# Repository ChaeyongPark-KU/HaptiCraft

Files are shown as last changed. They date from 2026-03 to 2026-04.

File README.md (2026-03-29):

# HaptiCraft: A Modular Multimodal Haptic Controller for Immersive VR

**HaptiCraft** is a modular, reconfigurable handheld controller designed to replicate the physical appearance, mass distribution, and rich multimodal haptic properties of virtual objects. By assembling cubic modules with distinct functions, users can create a customized physical proxy tailored to specific VR interactions.

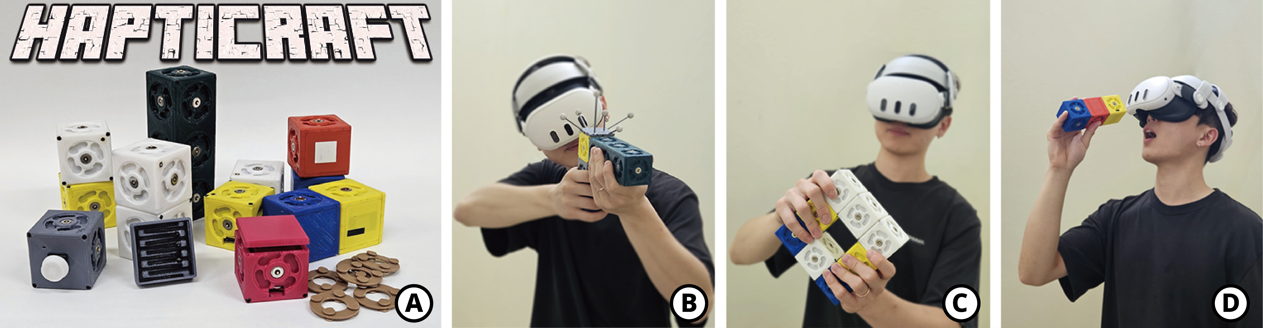
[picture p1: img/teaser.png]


## Key Features

* **Modular Shape Approximation**: Uses unit cube modules ($48 \times 48 \times 48$ mm) to build controllers that mimic the shape of virtual counterparts.
* **Multimodal Feedback**: Supports five distinct active haptic stimuli: **Vibration**, **Impact**, **Thermal**, **Variable Inertia**, and **Variable Stiffness**.
* **Dynamic Property Matching**: Features a variable inertia module that shifts internal mass to match the Moment of Inertia (MOI) of virtual objects.
* **Integrated Authoring Tool**: Includes a graphical "What-You-See-Is-What-You-Get" (WYSIWYG) tool for designing both physical forms and complex haptic timelines.

## System Architecture

HaptiCraft is built on three foundational pillars:

1.  **Hardware**: 3D-printed (PLA) modules containing MCUs (Wemos D1 mini; ESP8266), actuators, and a secure mechanical connection mechanism.
2.  **Firmware**: ESP8266-based code managing assembly detection, wireless mesh synchronization, and real-time haptic command execution.
3.  **Software**: A Unity-based authoring tool that exports designs in the **HaptiCraft Description Format (.hdf)**, a JSON-based schema for easy integration into VR projects.

## Repository Structure

This repository is organized into three main components:

* **/Hardware**: Includes CAD files (STL) for module housings and circuit schematics for the haptic drivers.
* **/Firmware**: ESP8266 source code for the Wi-Fi mesh communication and haptic rendering protocols.
* **/Software**: The Unity source code for the HaptiCraft authoring tool.

## Examples
### Haptic Modules
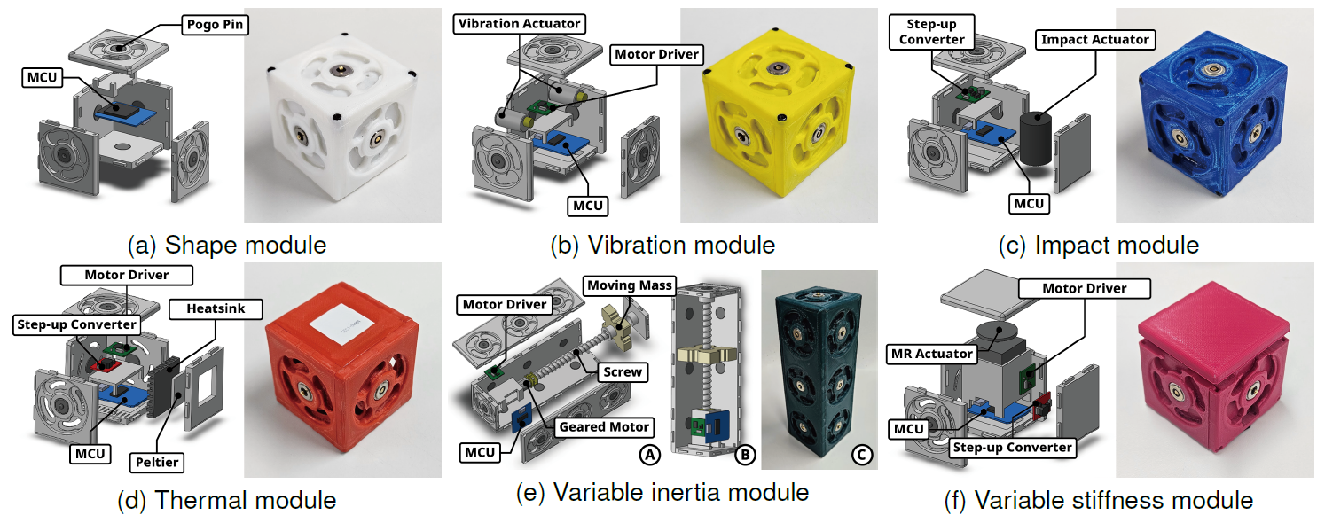
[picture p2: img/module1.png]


### utility Module and Connector
<p align="center">
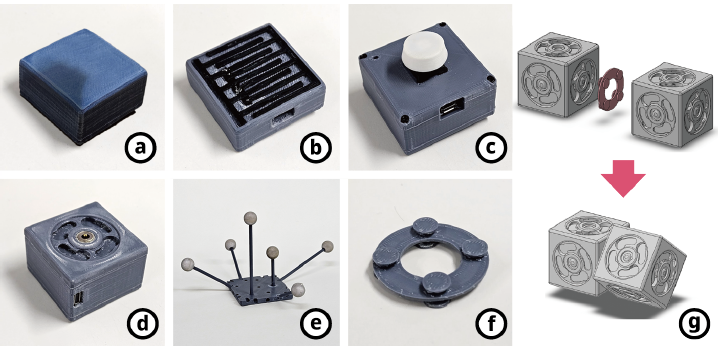
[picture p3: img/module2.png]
  
</p>

### Controller Authoring Tool
<p align="center">
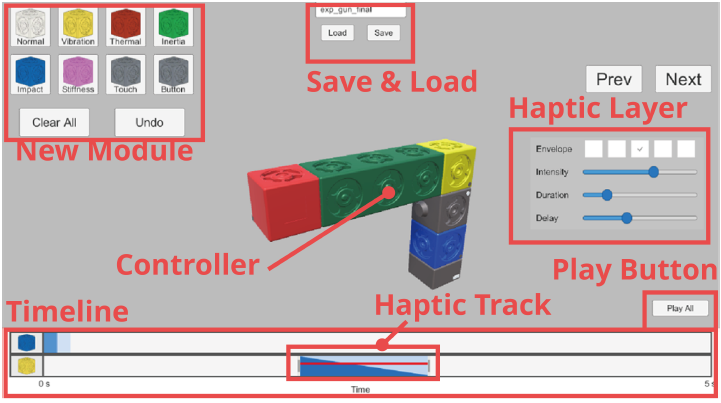
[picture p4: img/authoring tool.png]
  
</p>

## Citation
If you use HaptiCraft in your research, please cite our paper:
```
@article{Park2026HaptiCraft,
author = {Park, Chaeyong and Kim, Jeongwoo and Song, Yuk-Gwon and Kim, Sang-Youn and Choi, Seungmoon},
title = {HaptiCraft: A Modular Multimodal Haptic Controller for Immersive Virtual Reality Interactions},
journal = {IEEE transactions on visualization and computer graphics},
volume={XX},
number={X},
pages={XXXX--XXXX},
year={2026},
publisher={IEEE}
}
```

## Issues
If you encounter any issues, please feel free to contact us at chaeyong@korea.ac.kr.

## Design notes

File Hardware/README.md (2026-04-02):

# HaptiCraft Hardware

This folder contains the CAD files (STL) and electronic specifications for the **HaptiCraft** system. All haptic and utility modules are built around the [**ESP8266-based Wemos D1 Mini**](https://www.wemos.cc/en/latest/d1/d1_mini.html).

## Manufacturing & Assembly

* **3D Printing**: All housings are designed for modular assembly. For this research, parts were printed using a **Cubicon Single Plus 320C** with PLA filament. But, you can use any 3D printer for printing.
* **Module Faces**: Each STL file corresponds to a specific side of a cube, designed to be easily printed and assembled to house internal components.
* **Power & Connection**: Modules use [**magnetic pogo pins**](https://duertry.com/r/v2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) at the center of each face to enable both structural bonding and power sharing (up to 12V, 10A) across the entire assembly.

## Module-Specific Hardware Descriptions
Follow the schematics provided in this directory for each specific module type:

### 1. Shape Module
The structural unit of the system. It consists of the 3D-printed housing, the MCU, and 6 Pogo pins for connectivity, with no active haptic actuators.

<p align="center">
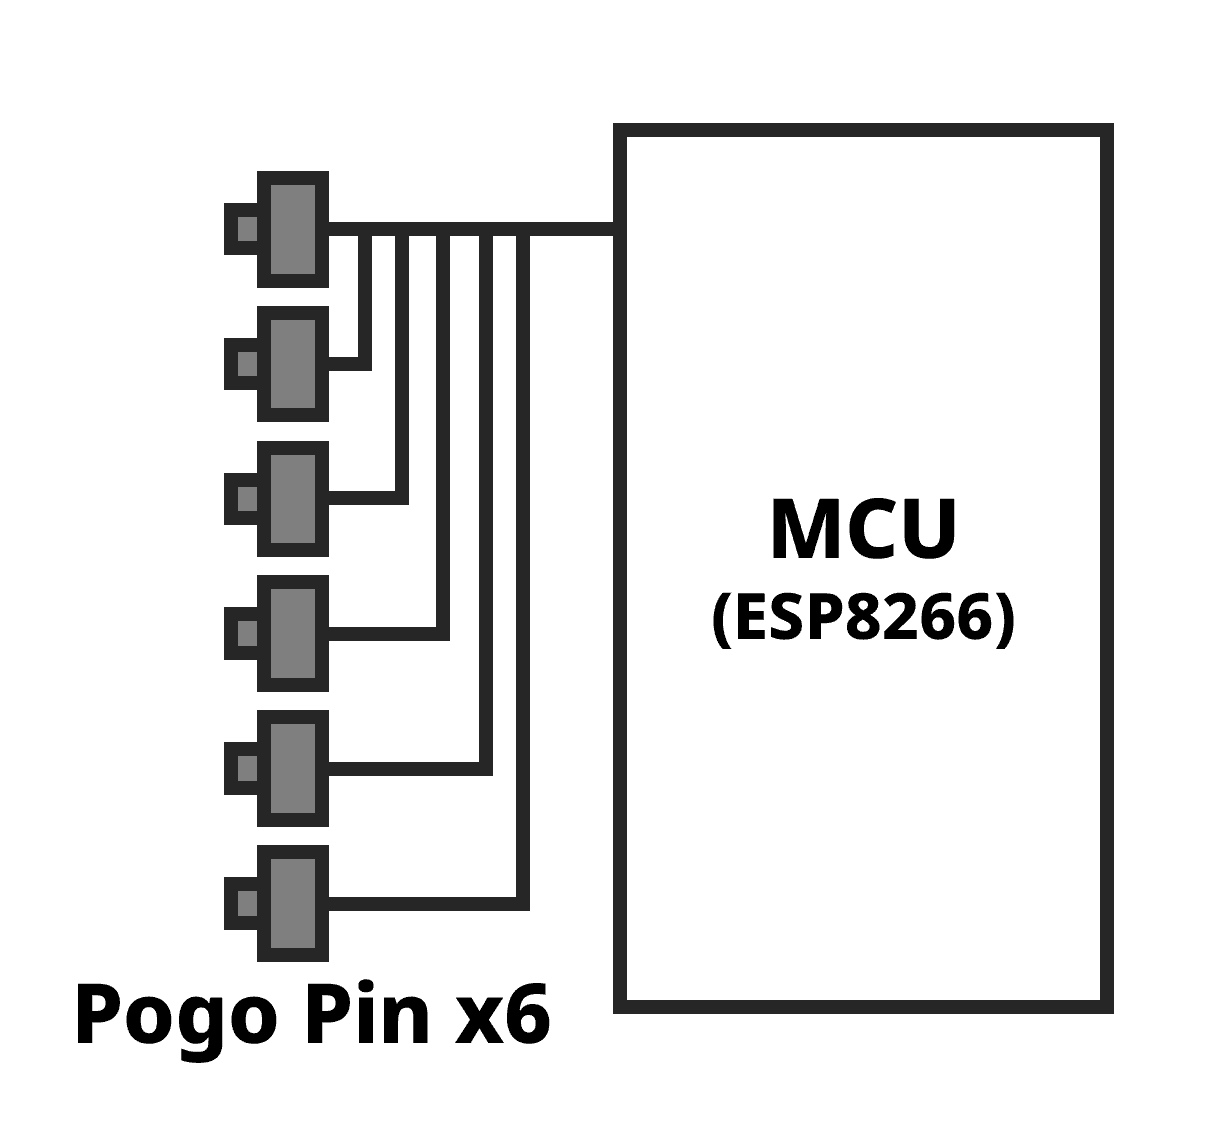
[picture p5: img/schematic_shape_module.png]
   
</p>

### 2. Vibration Module
Uses a motor driver to power two ERM motors for stable vibrotactile feedback.
* **ERM**: [D&J WITH Co., Ltd.; DVM1220](https://www.devicemart.co.kr/goods/view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).
* **Motor Driver**: [Pololu; BD65496MUV](https://www.rohm.co.kr/products/motor-actuator-drivers/dc-brush-motor/bd65496muv-product#productDetail).

<p align="center">
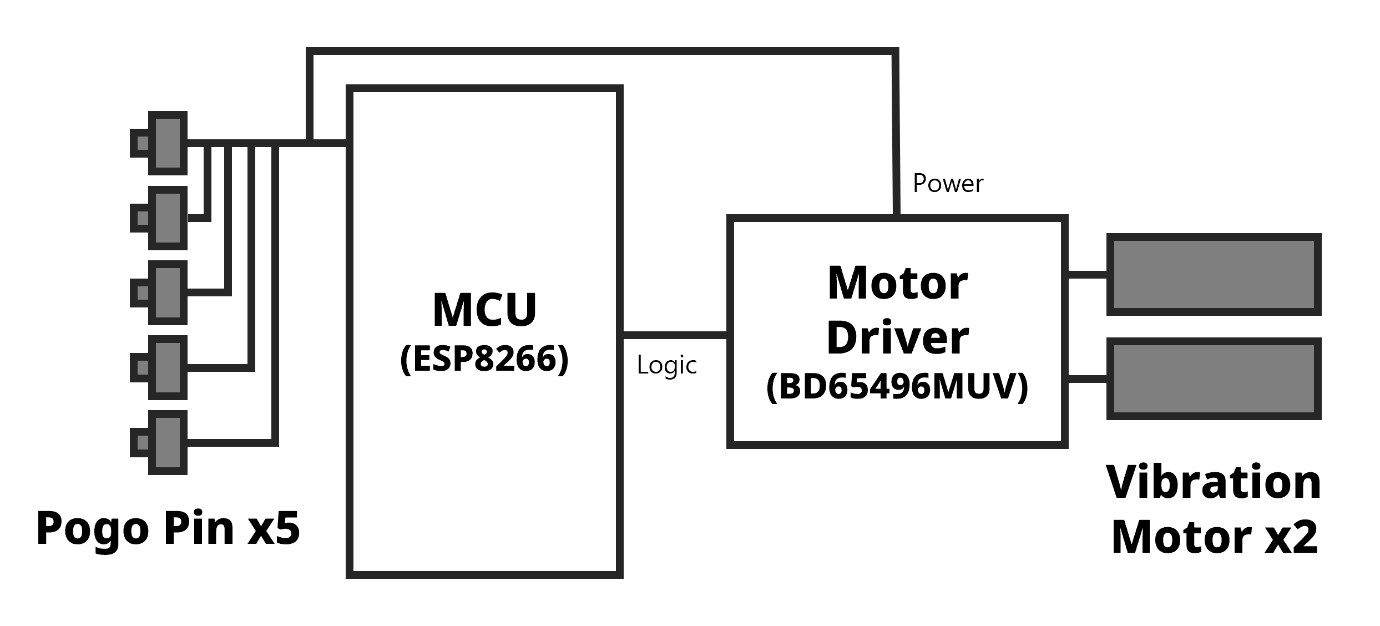
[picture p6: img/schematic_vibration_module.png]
   
</p>

### 3. Impact Module
Delivers short, strong impulses. Since it requires 5V, a step-up converter is integrated into the circuit.
* **Actuator**: [Acturonix; Digital Haptic Actuator](https://www.acturonix.com/).
* **Converter**: [WSTECH; DM06-V5](m.eleparts.co.kr/goods/view?no=4107103).

<p align="center">
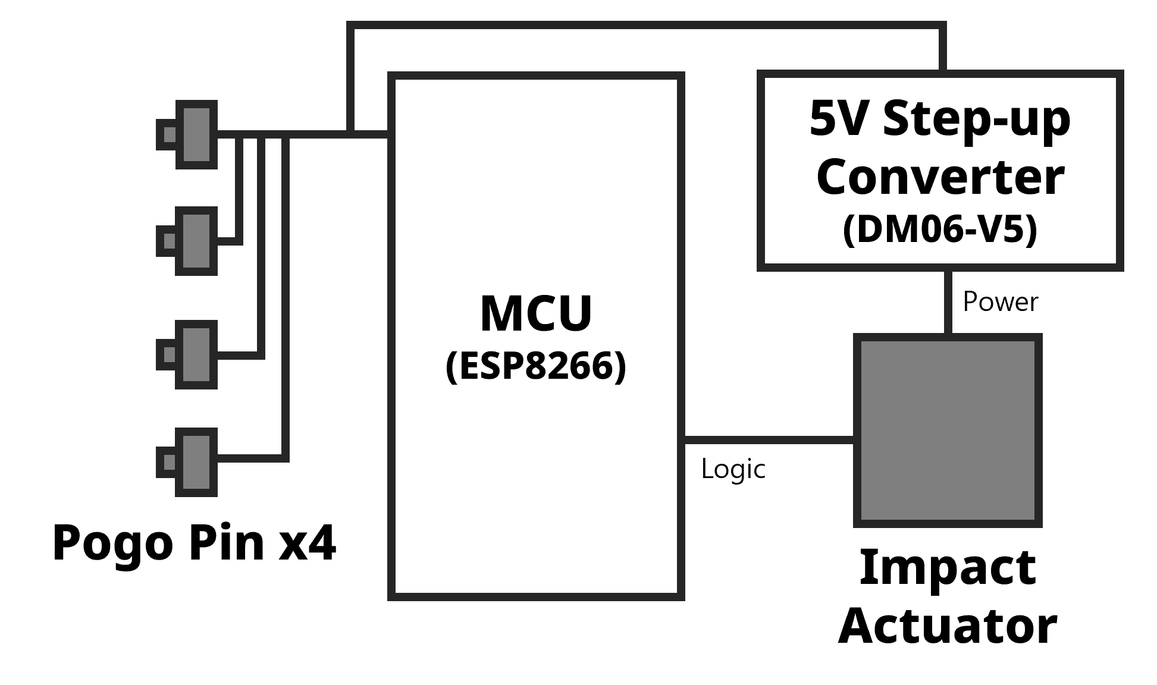
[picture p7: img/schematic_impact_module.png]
   
</p>

### 4. Thermal Module
Provides temperature feedback using a Peltier element. The assembly includes a step-up converter, motor driver, and a heatsink for effective thermal management.
* **Peltier**: [20×20 mm; SMG TES1-4903](https://www.devicemart.co.kr/goods/view?no=10894480).
* **Motor Driver**: [Pololu; BD65496MUV](https://www.rohm.co.kr/products/motor-actuator-drivers/dc-brush-motor/bd65496muv-product#productDetail).
* **Converter**: [WSTECH; DM13-V5](https://www.navimro.com/p/K92841578/?srsltid=AfmBOopcCdm5g3zLqHN5-aAA_jKeQ_9SND-a58UxNgDZ9oHb2oCQjKNd).

<p align="center">
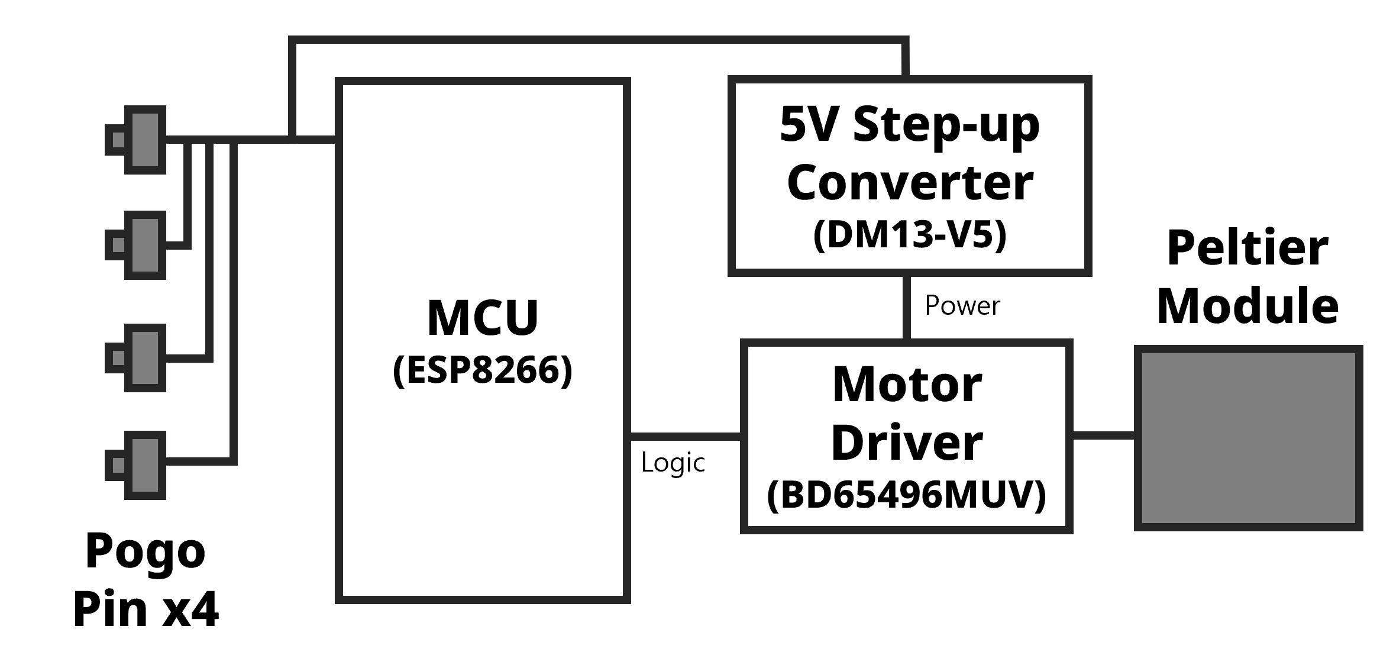
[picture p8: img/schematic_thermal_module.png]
   
</p>

### 5. Variable Inertia Module
Converts rotational motion into linear motion via a geared motor to shift the position of a **brass moving mass**. The moving mass can be weighted further using the uploaded weight-add files.
* **Gear Motor**: [N20; SZH-GNP095](https://www.icbanq.com/P008113428?srsltid=AfmBOoqd4h_dOW6KhbtmznncK5vQkRHJzLvjkogEKoTrAjK_nVLmlyeV).
* **Motor Driver**: [Pololu; BD65496MUV](https://www.rohm.co.kr/products/motor-actuator-drivers/dc-brush-motor/bd65496muv-product#productDetail).

<p align="center">
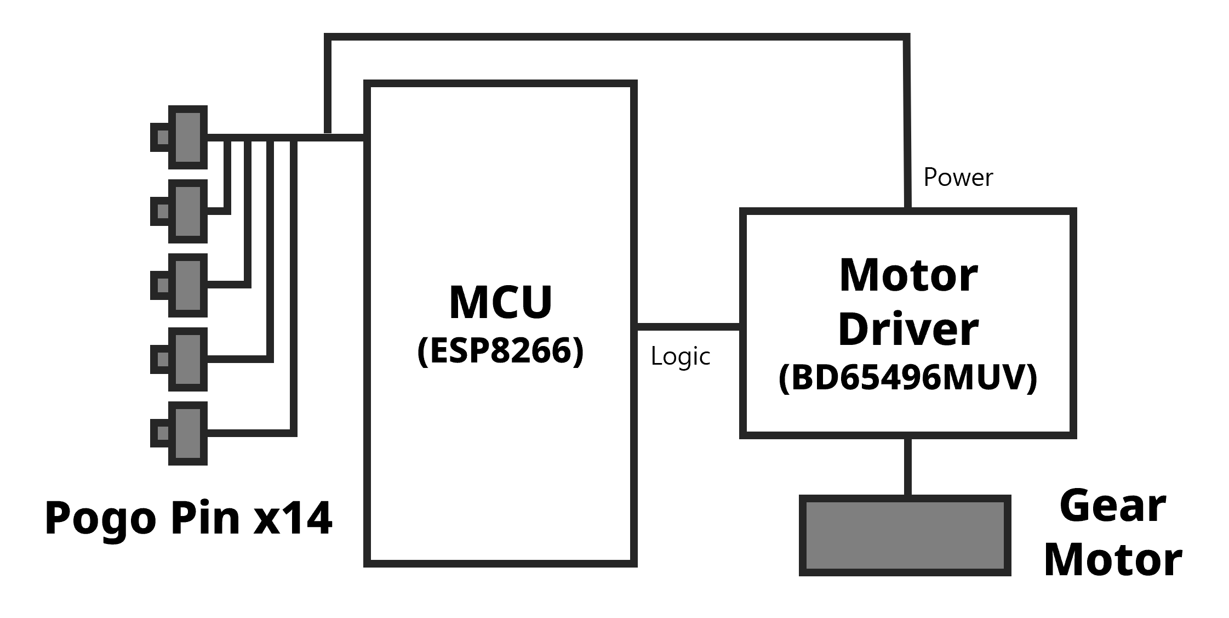
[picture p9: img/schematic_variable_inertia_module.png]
   
</p>

### 6. Variable Stiffness Module
Adjusts surface softness using a custom variable-damping actuator. The internal circuit is based on the mechanism described in [[46]](https://journals.sagepub.com/doi/10.1177/1045389X13493359). All necessary CAD files for the spring-loaded structure are provided.

<p align="center">
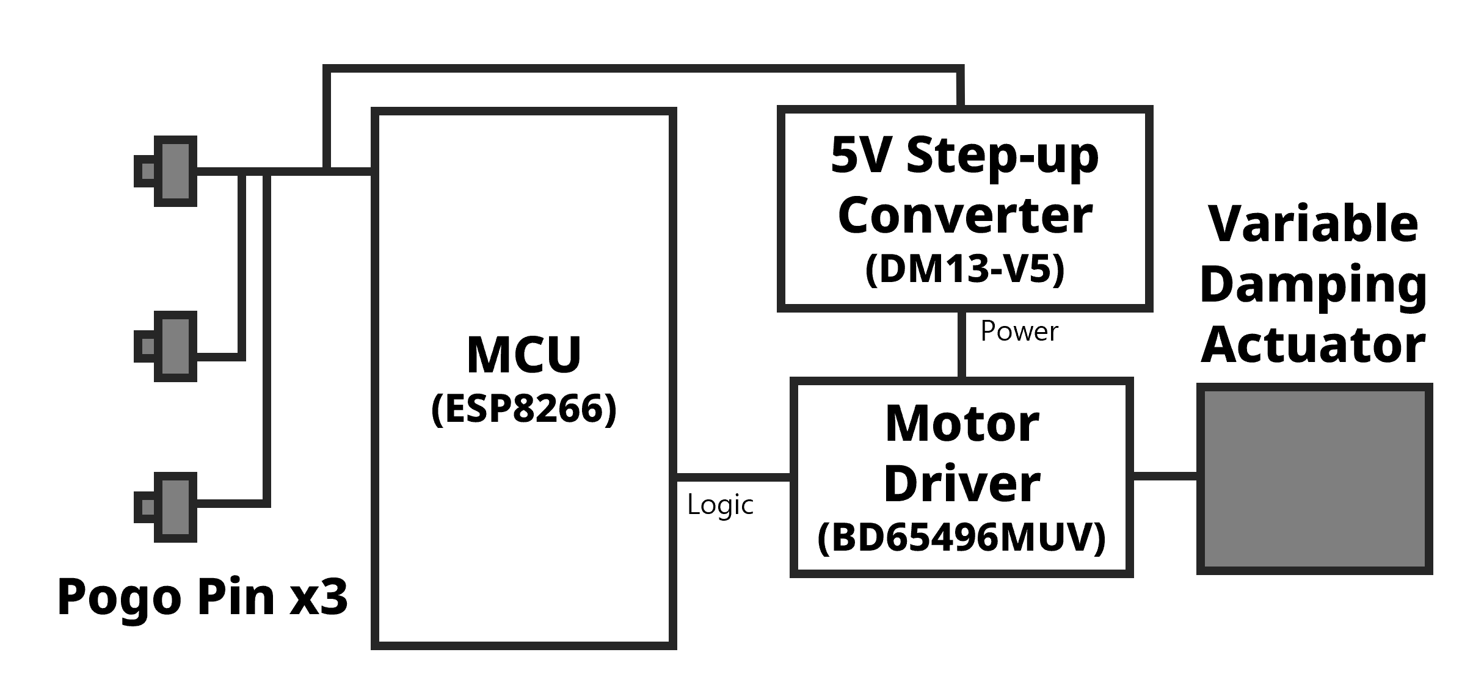
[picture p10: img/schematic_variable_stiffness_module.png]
   
</p>

### 7. Communication Module
A utility module containing only the MCU. It must be loaded with the `masterModule` firmware to act as the serial-to-mesh gateway.

### 8. Button Module
A 3D-printed housing embedded with a standard **mechanical keyboard switch** (linear switch) for user input.

<p align="center">
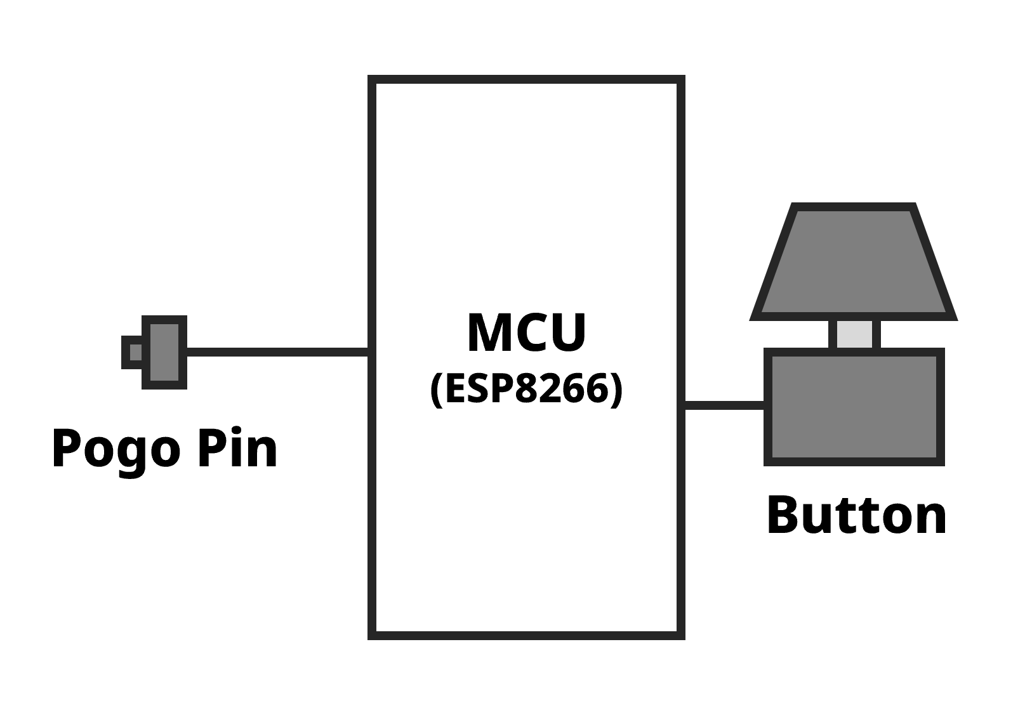
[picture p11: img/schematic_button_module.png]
   
</p>

### 9. Touch Module
The top panel is printed using **conductive filament**. The circuit detects a touch when a finger bridges the filament paths, completing the electrical connection.

<p align="center">
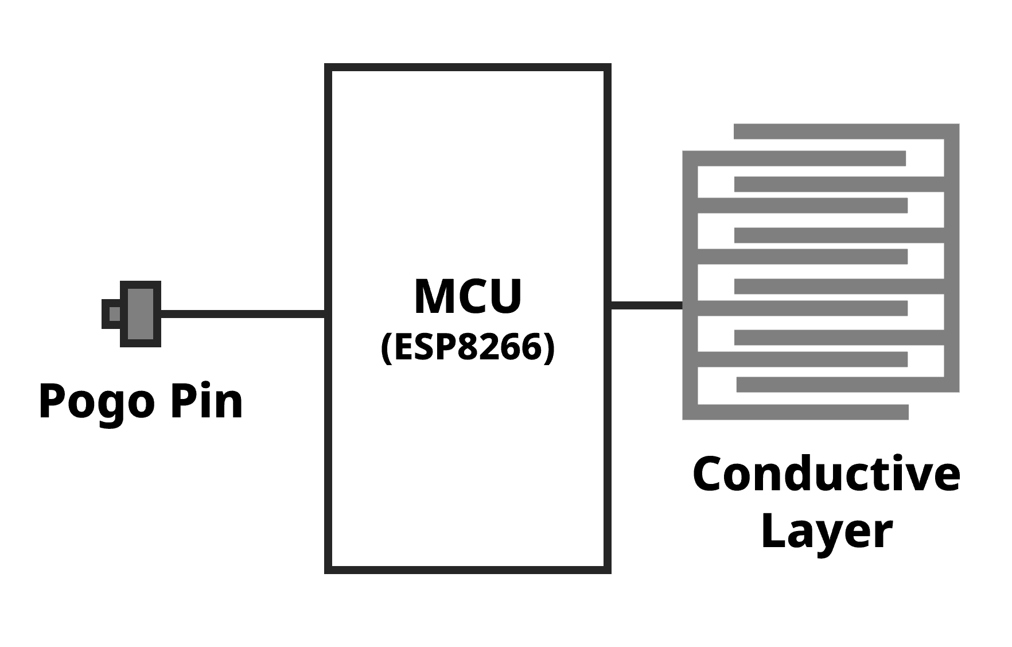
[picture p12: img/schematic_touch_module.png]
   
</p>

### 10. Power Module
Houses a **LiPo battery** (3.7V, 1200 mAh) and a charging circuit to provide untethered power to the entire HaptiCraft assembly.

<p align="center">
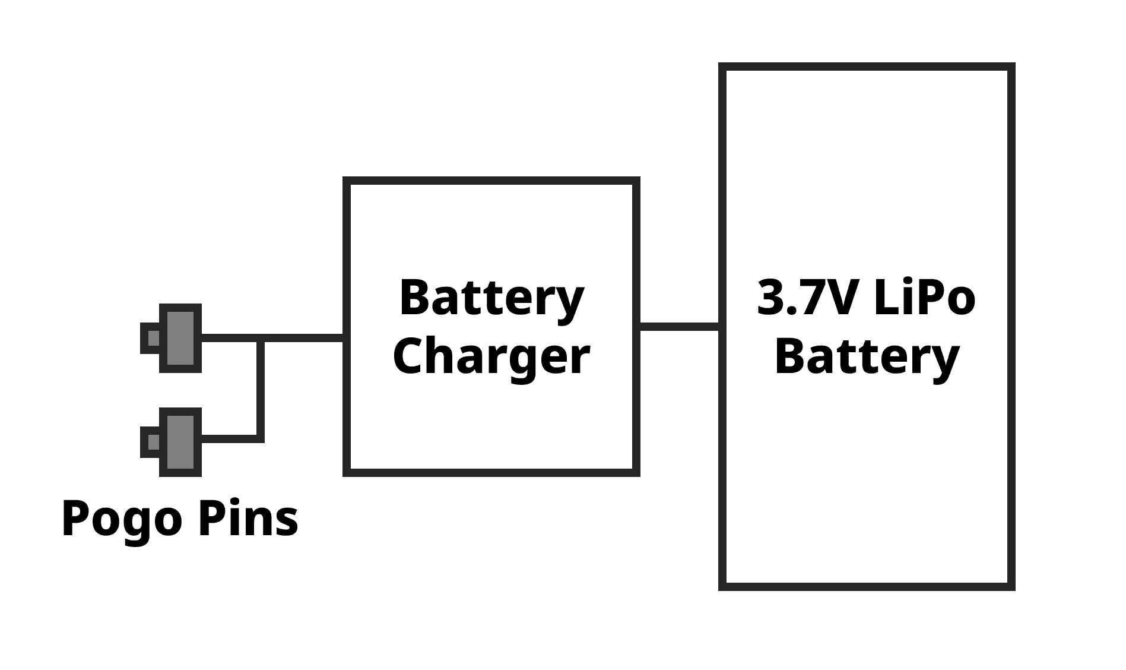
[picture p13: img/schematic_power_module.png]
   
</p>

### 11. Tracking Module
Supports optical tracking (e.g., [Optitrack](https://optitrack.com/)). It is recommended to print various pillars and body types to create unique rigid-body marker configurations for VR tracking.

### 12. Connector Module
A 3D-printed part featuring four embossed poles that secure the mechanical connection between modules.

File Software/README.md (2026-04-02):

# **HaptiCraft Authoring Tool**

HaptiCraft authoring tool is a Unity-based tool designed for creating modular haptic controllers and designing custom haptic feedback patterns. This tool supports the entire workflow from virtual assembly to physical implementation and haptic signal synchronization.

<p align="center">
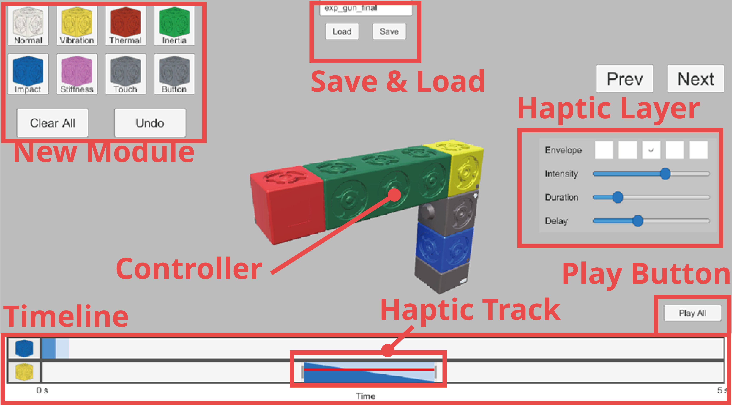
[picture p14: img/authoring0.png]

</p>

## **Preparation**

### **Hardware Requirements**

- **Communication Module:** Connect a communication module to your PC via USB.
- **Serial Port:** Identify the COM port number (Windows) assigned to the communication module.

### **Software Requirements**

- **Unity Version:** Tested and verified on **Unity 2022.3 (LTS)**.
- **Package:** Import the provided `.unitypackage` into your Unity project.

### **Project Configuration**

1. Go to **Project Settings \> Player \> Configuration**.
2. Set **Api Compatibility Level** to **.NET Framework**.
3. Open the main scene: Assets/Scenes/HaptiCraft.unity.
4. In the **Hierarchy**, find Authoring Utils \-\> Serial Manager.
5. Set the **Port Number** in the Inspector to match your communication module's serial port.

## **Basic Controls**

<p align="center">

| **Action** | **Input** |
| --- | --- |
| **Rotate Controller** | Left Click \+ Drag  |
| **Move Controller** | Wheel Click \+ Drag |
| **Zoom In / Out** | Wheel Scroll |
</p>

## **Authoring Workflow**

The tool consists of three main phases to guide you through the creation process.

### **1\. Controller Design Phase**

This is where you design the physical structure of your virtual modular controller.

<p align="center">
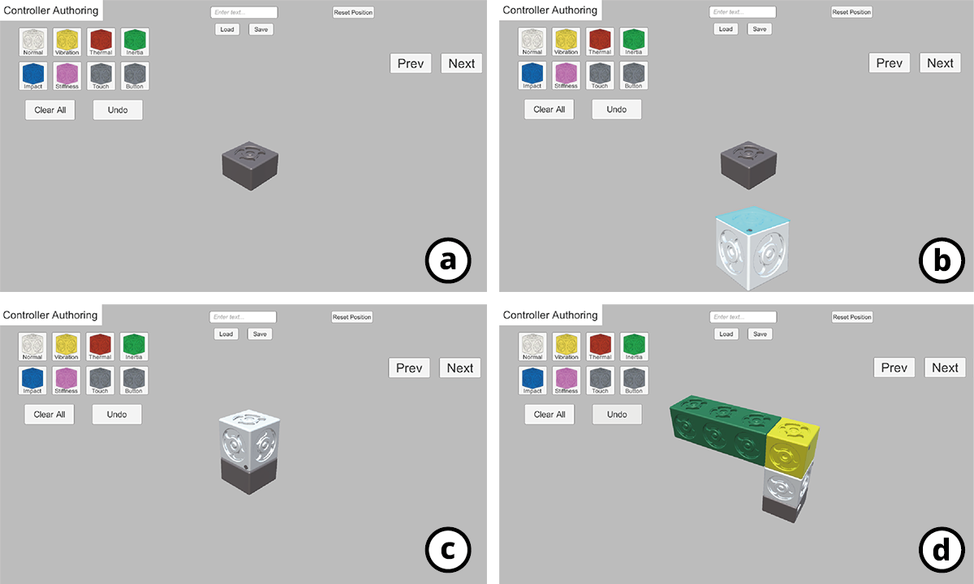
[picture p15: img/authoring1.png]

</p>

- **Add Modules:** Click the module buttons (top-left) to spawn a module at the bottom-center of the screen.
- **Connect Modules:** Select a specific face of the new module and then the face on the existing controller you wish to connect to.
- **Rotate:** Use the **Arrow Keys** to rotate the module before finalizing.
- **Confirm:** Press the **Return (Enter)** key to finalize the connection.
- **Next:** Once the controller is finished, click the **Next** button (top-right).

### **2\. Haptic Assembly Phase**

Design and edit haptic signals for the assembled controller.

<p align="center">
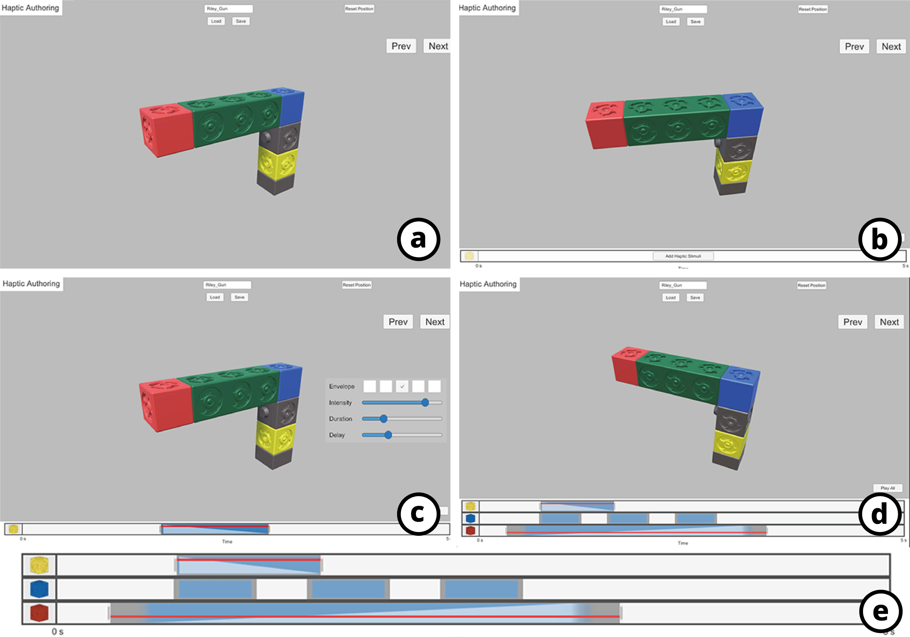
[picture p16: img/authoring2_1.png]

</p>

- **Module Selection:** Left-click on any haptic-capable module to create a stimulus.
- **Edit Haptic Effects:** Use the **Haptic Layer** (right) and the **Timeline/Haptic Track** (bottom) to adjust the timing, duration, and intensity of the feedback.

### **3\. Implementation Phase**

This phase helps you assemble the physical hardware corresponding to your virtual design.

- **Assembly Guide:** Starting from `Power module`, the virtual module to be connected next will **blink**.
- **Detection:** Once `Communication Module` recognizes the physical connection, the next module in the sequence will start blinking.
- **Skip:** You can skip this phase and proceed to the next by clicking the **Next** button without connecting physical modules.

#### **Supported Modules:**

- **Vibration Module:** Envelope, Intensity, Duration, Delay.
- **Thermal Module:** Mode (Cold / Hot), Intensity, Duration, Delay.
- **Inertia Module:** Direction, Duration.
- **Impact Module:** Repetition, Delay.
- **Stiffness Module:** _(Currently disabled)_
- **Button Module:** Click detection.
- **Touch Module:** Touch detection.

## **Save / Load**

You can save or load your controller designs and haptic patterns at any time.

- Enter a filename in the **Input Field** at the top of the screen.
- Click **Save** to store the current configuration or **Load** to restore a previous one.

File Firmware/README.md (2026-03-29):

# HaptiCraft Firmware

This folder contains the ESP8266-based firmware for the **HaptiCraft** system. The system operates on a **Master-Slave architecture** using a Wi-Fi mesh network to deliver synchronized, multimodal haptic feedback.

## System Architecture

The firmware is divided into two primary roles:

### 1. Master Module (`/masterModule`)
The Master Module (referred to as the **Communication Module** in the paper) serves as the central bridge between the PC and the haptic controller.
* **Serial Gateway**: Receives high-level haptic commands from the PC via Serial communication (115200 baud).
* **Mesh Management**: Manages a list of all physically connected haptic modules, assigning names and tracking their connection status.
* **Connection Checker**: Periodically broadcasts check signals ("D") to verify if modules are still attached; it automatically removes timed-out nodes from the registry.
* **Command Broadcasting**: Parses PC commands and broadcasts them to the entire Wi-Fi mesh.

### 2. Haptic Modules (`/hapticModule`)
Every individual haptic module runs the same unified firmware, with its specific behavior defined by a module-type constant.
* **Multimodal Execution**: Supports Vibration (ERM), Thermal, Variable Inertia, Impact, and Variable Stiffness.Each module contains its own scheduler to handle timing-critical tasks like PWM generation for waveforms.
* **Input Detection**: Input modules (Touch/Button) detect user interaction and send status updates ("CO" for contact on, "CF" for contact off) back to the Master.

## Communication Flow
<p align="center">
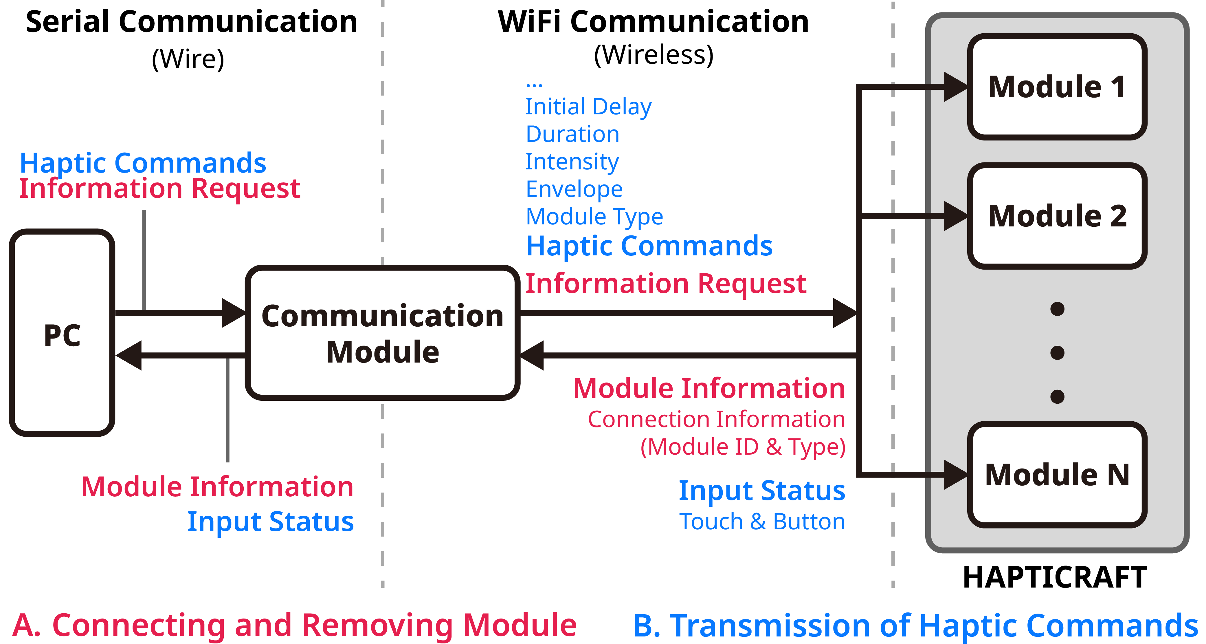
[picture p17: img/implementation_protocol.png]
   
</p>

Refer to the diagram below for the data transmission path:

1.  **PC &rarr; Master**: Sends encoded strings (e.g., `$11V101000`) via Wire.
2.  **Master &rarr; Mesh**: Broadcasts the command wirelessly to all nodes.
3.  **Haptic Module**: If the `nodeName` matches the prefix in the command, the module parses the parameters and triggers the actuator.

## Configuration & Upload

### 1. Prerequisites
* **Hardware**: Wemos D1 Mini (ESP8266).
* **Libraries**: 
    * `painlessMesh` (for Wi-Fi Mesh networking).
    * `ArduinoVector` (for node management).
    * `ArduinoJson` (required by painlessMesh).

### 2. Defining Module Types
Before uploading to a **Haptic Module**, you must define its identity in `moduleDefinition.h`:

```cpp
// moduleDefinition.h
#define VIBERM // Uncomment the specific module type (VIBERM, THERM, IMPACT, etc.)
String nodeName = "11"; // Set a unique 2-digit ID for the module
```

Here is the updated **Command Format** section for your `README.md`. This version specifically reflects the broadcasting logic found in your `masterModule.ino` and the parsing behavior in `hapticModule.ino`.

### 3. Command Format & Broadcasting Logic

HaptiCraft utilizes a **Global Broadcast** strategy to ensure synchronized multimodal effects across multiple modules.

#### **Transmission Protocol**
1.  **PC → Master**: The PC generates a single aggregated string containing all haptic instructions for the intended modules. This string starts with the `$` prefix and appends information for every module to be operated.
2.  **Master → Mesh**: The Master Module identifies the `$` header from the serial input and **broadcasts the command exactly as received** to the entire Wi-Fi mesh network using `mesh.sendBroadcast(inString)`.
3.  **Module-Side Parsing**:
    * Every Haptic Module in the mesh receives the full broadcasted string.
    * Each module parses the string to find segments that begin with its own unique `nodeName` (e.g., "11").
    * If a match is found, the module extracts the specific haptic parameters, stores them in a local command buffer, and executes the rendering task.

#### **Command Syntax**
The aggregated string sent by the PC follows this structure: `$[ModuleID][Command],[ModuleID][Command]...`

| Module Type | Haptic Command (Example) | Description |
| :--- | :--- | :--- |
| **Vibration** | `11V[Env][Int][Dur][Del]` | `11V1101005`: Flat, max intensity, 1s duration, 0.5s delay. |
| **Thermal** | `21T[Dir][Int][Dur][Del]` | `21T1105010`: Hot, max intensity, 5s duration, 1s delay. |
| **Variable Inertia** | `31M[Dir][Dist][Del]` | `31M01005`: Move 10mm upward, 0.5s delay. |
| **Variable Impact** | `41P[Del][Count]` | `41P1001`: Trigger 1 impact after 1s delay. |
| **Variable Stiffness** | `61S[Int][Dur][Del]` | `61S100500`: Max stiffness, 5s duration, 0.5s delay. |

* **Example PC Command**: `$11E1101005,41P1001`
    * *Master Module*: Broadcasts the entire string to the mesh.
    * *Module 11*: Extracts `E1101005` and starts vibration.
    * *Module 41*: Extracts `P1001` and triggers an impact.

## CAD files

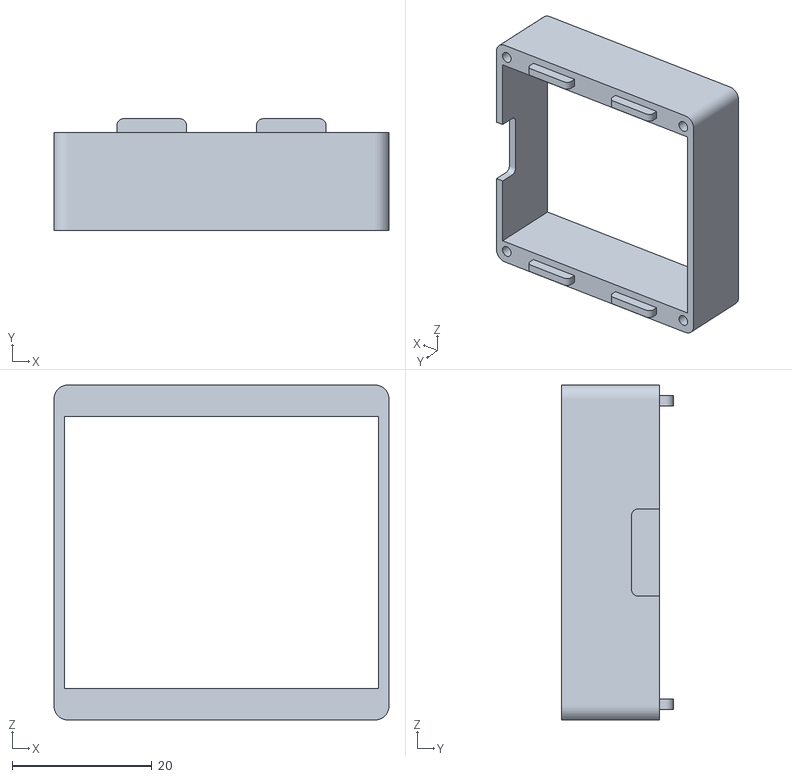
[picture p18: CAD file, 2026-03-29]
Hardware/Button Module/2_side.STL
48.0 x 16.0 x 48.0

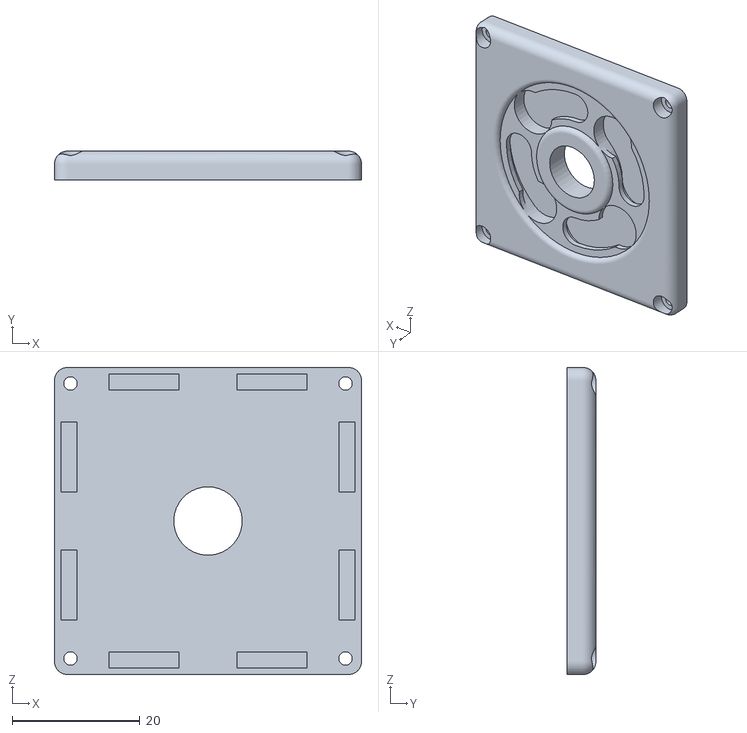
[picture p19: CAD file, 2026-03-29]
Hardware/Communication Module/1_bottom.STL
48.0 x 4.50 x 48.0

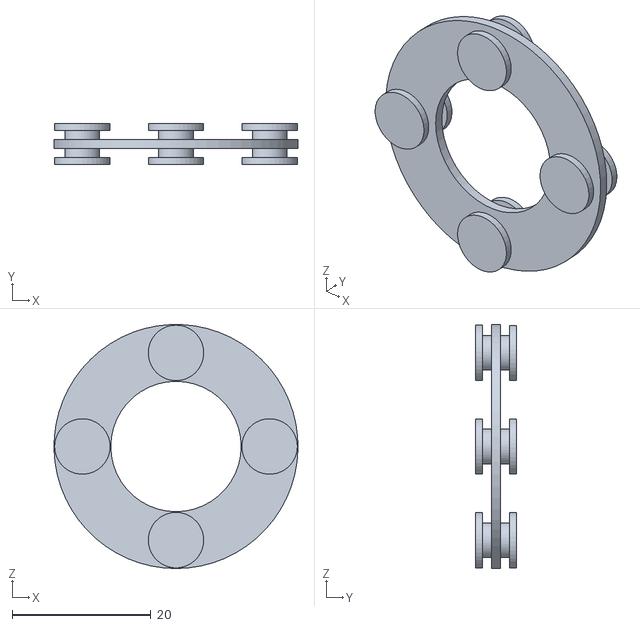
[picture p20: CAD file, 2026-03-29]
Hardware/Connector/1_connector.STL
35.2 x 5.87 x 35.2

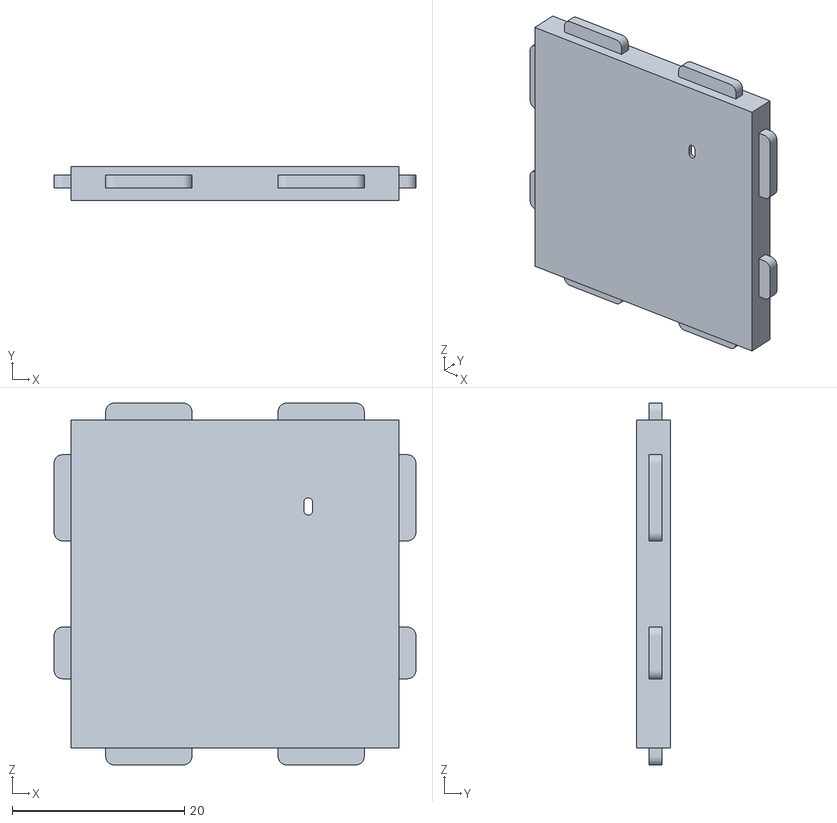
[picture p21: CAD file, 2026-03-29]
Hardware/Impact Module/1_bottom.STL
42.0 x 4.00 x 42.0

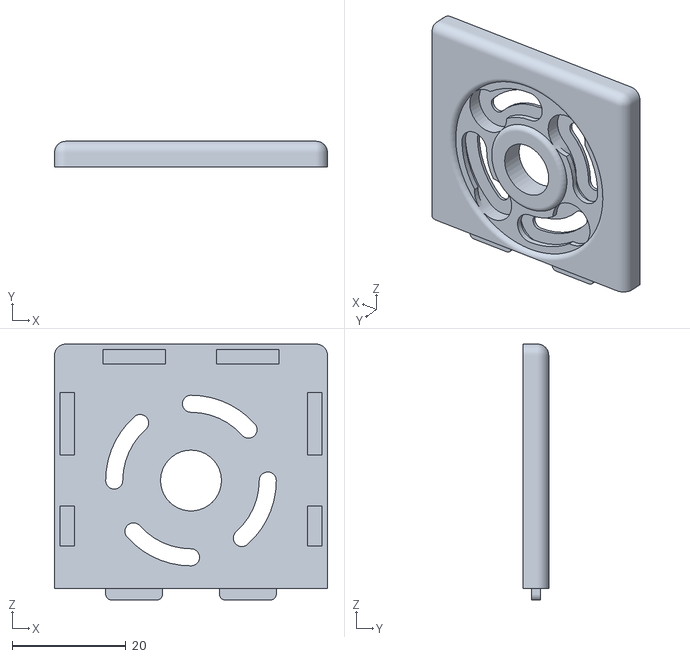
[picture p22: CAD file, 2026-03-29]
Hardware/Thermal Module/6_top.STL
48.0 x 4.50 x 45.0

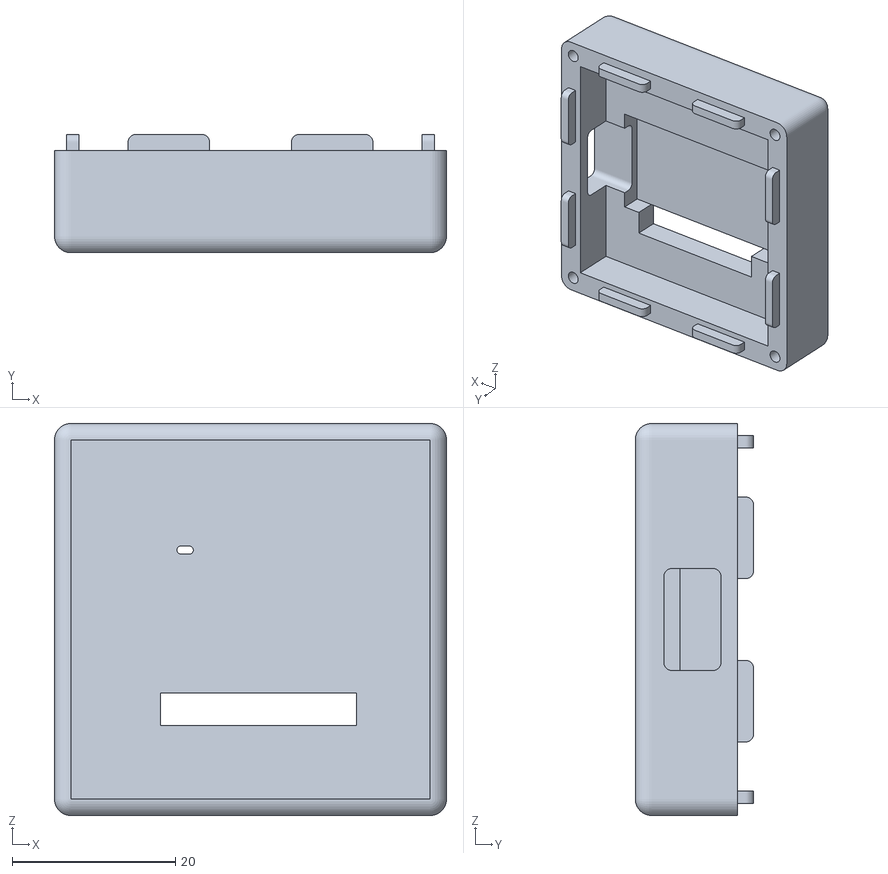
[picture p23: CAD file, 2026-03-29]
Hardware/Touch Module/2_side and top.STL
48.0 x 14.5 x 48.0

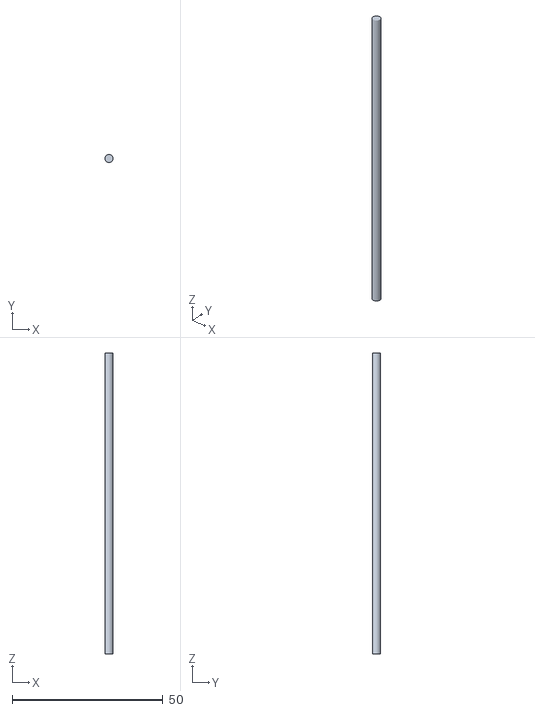
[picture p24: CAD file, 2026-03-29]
Hardware/Tracking Module/5_rod 100mm.STL
2.75 x 2.75 x 100.0

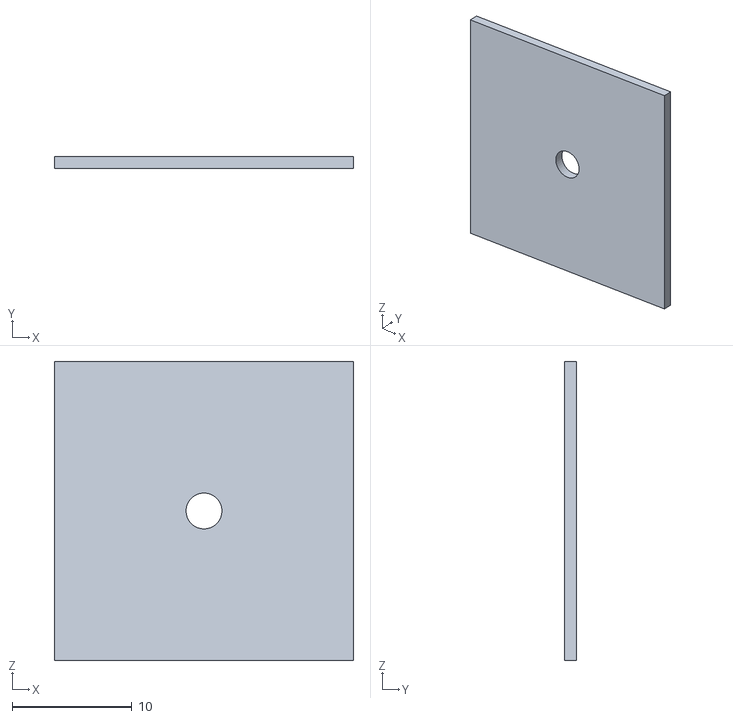
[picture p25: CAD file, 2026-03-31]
Hardware/Variable Damping Actuator/8_stopper.STL
25.0 x 1.00 x 25.0

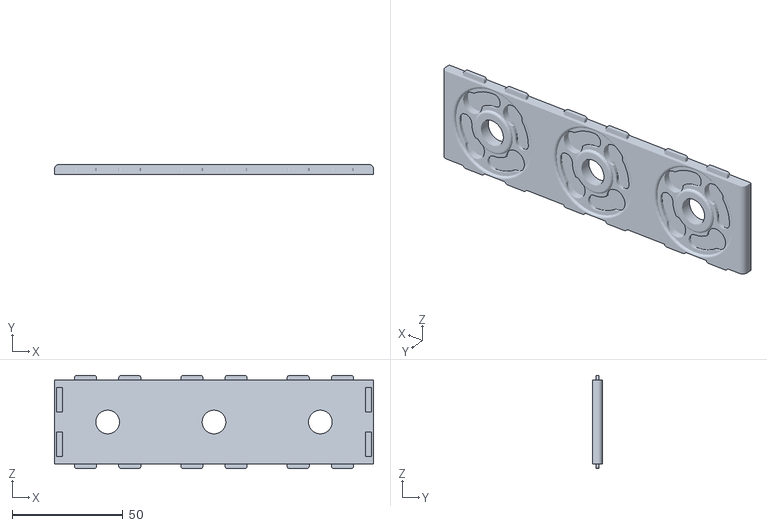
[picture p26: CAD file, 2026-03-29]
Hardware/Variable Inertia Module/1_bottom.STL
144.0 x 4.50 x 42.0

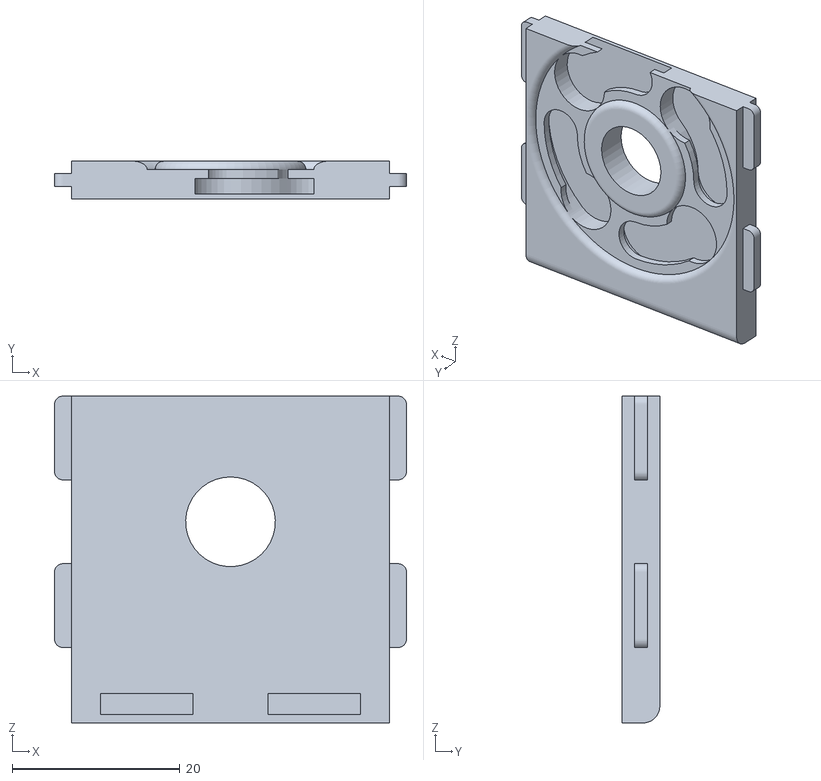
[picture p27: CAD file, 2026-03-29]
Hardware/Variable Stiffness Module/3_side-left.STL
42.0 x 4.50 x 39.0

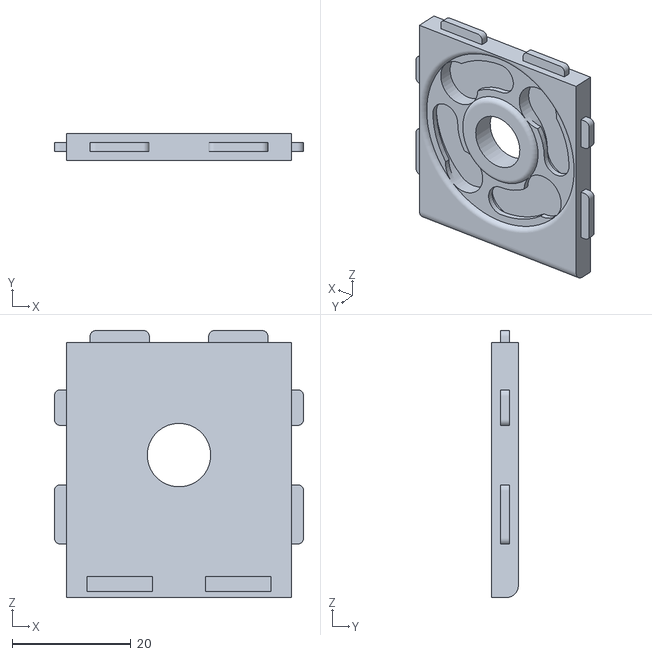
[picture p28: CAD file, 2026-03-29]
Hardware/Vibration Module/3_side-left.STL
42.0 x 4.50 x 45.0

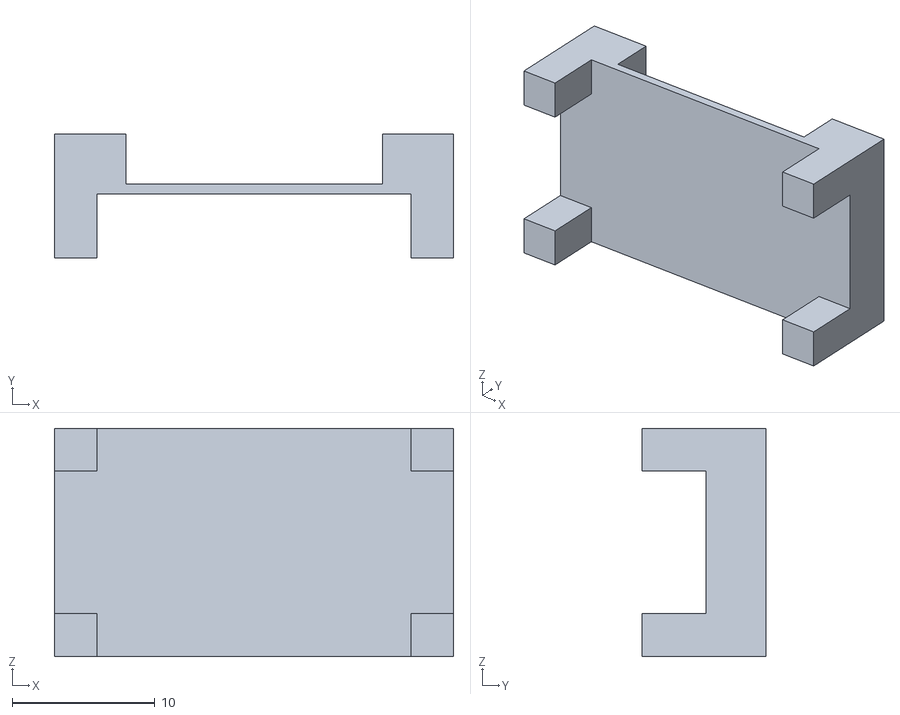
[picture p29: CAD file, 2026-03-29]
Hardware/Button Module/4_support.STL
28.0 x 8.70 x 16.0

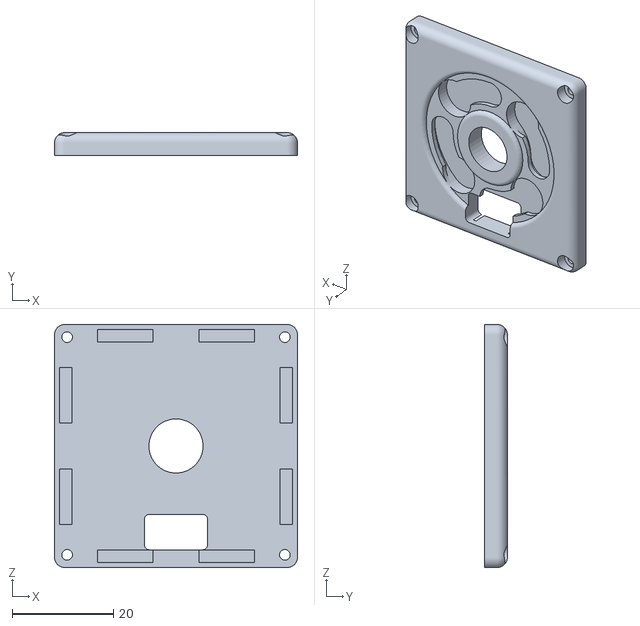
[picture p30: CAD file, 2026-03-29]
Hardware/Impact Module/5_side-right.STL
48.0 x 4.50 x 48.0

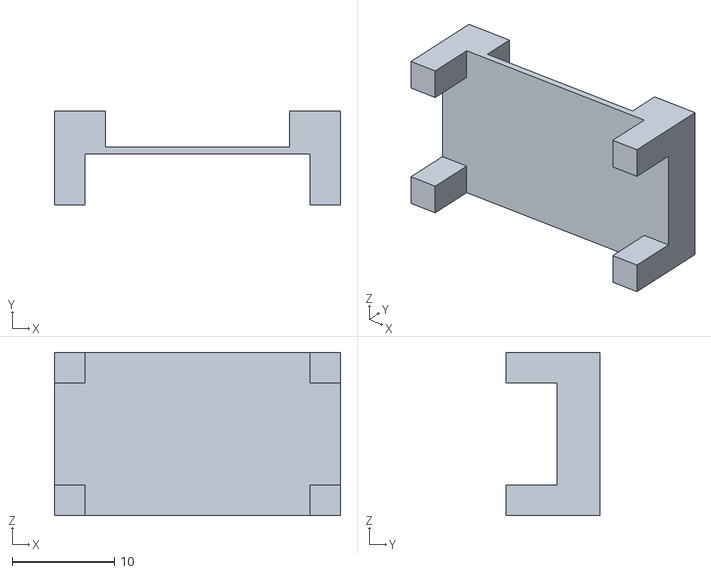
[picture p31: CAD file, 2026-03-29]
Hardware/Shape Module/7_support.STL
28.0 x 9.20 x 16.0

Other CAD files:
Hardware/Shape Module/6_top.STL
Hardware/Power Module/3_top for single side.STL
Hardware/Button Module/1_bottom.STL
Hardware/Button Module/3_top.STL
Hardware/Impact Module/2_side-front.STL
Hardware/Impact Module/3_side-left.STL
Hardware/Impact Module/4_side-back.STL
Hardware/Impact Module/6_top.STL
Hardware/Impact Module/7_support.STL
Hardware/Power Module/1_bottom-single side.STL
Hardware/Power Module/2_bottom-double side.STL
Hardware/Power Module/5_holder.STL
Hardware/Shape Module/1_bottom.STL
Hardware/Shape Module/2_side-front.STL
Hardware/Shape Module/4_side-back.STL
Hardware/Shape Module/5_side-right.STL
Hardware/Thermal Module/1_bottom.STL
Hardware/Thermal Module/2_side-front.STL
Hardware/Thermal Module/3_side-left.STL
Hardware/Thermal Module/4_side-back.STL
Hardware/Thermal Module/5_side-right.STL
Hardware/Thermal Module/7_support.STL
Hardware/Touch Module/3_touch pannel 1.STL
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

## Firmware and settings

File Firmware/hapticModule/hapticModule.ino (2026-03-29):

/****
 *  Firmware for HaptiCraft (IEEE TVCG 2026)
 *  Author: Chaeyong Park
 *  Copyright (c): 2026. AXIS Laboratory, Korea University
 *  WEMOS D1 MINI (ESP8266)
 *
 *  Haptic modules
 * 
 *  Vibration (ERM) parameters: VABBCCDD (10~19)
 *  A: Envelope (0:flat, 1:increase, 2:decrease, 3:in-decrease, 4:de-increase)
 *  BB: Intensity (00-10)
 *  CC: Duration (x100ms; 00-99)
 *  DD: Initial delay (x100ms; 00-99)
 *  Example: V1101005 (flat, full intensity, 1second, after 0.5s)
 *
 *  Thermal Parameters: TABBCCDD (20~29)
 *  A: Direction (0: cool; 1: hot)
 *  BB: Intensity (00-10)
 *  CC: Duration (x100ms; 00-99)
 *  DD: Initial delay (x100ms; 00-99)
 *  Example: T1105010 (hot, full intensity, 5seconds, after 1s)
 *
 *  Variable Interia Parameters: MABBCC (30~39)
 *  A: Direction (0: upward, 1: downward)
 *  BB: Distnace (00-99: mm)
 *  CC: Initial delay (x100ms; 00-99)
 *  Example: M01005 (10mm movement to upward direction, after 0.5s)
 * 
 *  Impact Parameters: PAABB (40~49)
 *  AA: Initial delay (x100ms; 00-99)
 *  BB: Initial delay (x100ms; 00-99)
 *  Example: P10 (Impact rendering after 1s)
 *  
 *  Touch (50~59)
 *  
 *  Variable Stiffness Parameters: SAABBCC (60-69)
 *  AA: Intensity (00-10)
 *  BB: Duration (00-99)
 *  CC: Initial Delay (x100ms; 00-99)
 *  Example: S100500 (Full intensity, 5s, after 0.5s)
 *  
 *  Vibration (LRA) parameters: LAABBCC (90~99) *Not implemented yet
 *  AA: Intensity (00-10)
 *  BB: Frequency (Hz x 10; 00-99)
 *  CC: Duration (ms x 100; 00-99)
 *  Example: L101010
 *  
 *  I: Information
 *  D: Check for delete
 *  H: Handshake for checking
 */

#include "painlessMesh.h"
#include "moduleDefinition.h"
#include "waveform.h"
#include <Vector.h>

#define ELEMENT_COUNT_MAX 20

Scheduler userScheduler;
painlessMesh mesh;
bool isOn = false;
uint32_t masterID;

enum PHASE {
  PHASE_DELAY,
  PHASE_HAPTICGEN
};

void connectionChecker();
Task taskConnectionChecker(500 * TASK_MILLISECOND, TASK_FOREVER, &connectionChecker); 

void connectionChecker() {
  if (isOn) {
    digitalWrite(LED_BUILTIN, LOW);
  } else {
    digitalWrite(LED_BUILTIN, HIGH);
  }
  isOn = !isOn;
}

/* Vibration (ERM) */
#ifdef VIBERM
struct sVibrationERM {
  int pinPS;
  int pinDIR;
  int pinEN;
  int pinPWM;
  int envelope;
  int intensity;
  int duration;
  int initialDelay;
  PHASE phase;
  int cnt;
  String storage_array[ELEMENT_COUNT_MAX];
  Vector<String> commands;
  int commandIndex;
  short *waveform;
};
struct sVibrationERM hapticParams;

/* Haptic rendering function for ERM vibration */
void hapticRendering();
Task taskHapticRendering(10 * TASK_MILLISECOND, TASK_FOREVER, &hapticRendering); 

/* Reset haptic parameters for ERM vibration */
void resetHapticParams(struct sVibrationERM *_hapticParams) {
  Serial.println("Reset Vibration Parameters");
  _hapticParams->envelope = 0;
  _hapticParams->intensity = 0;
  _hapticParams->duration = 0;
  _hapticParams->initialDelay = 0;
  _hapticParams->phase = PHASE_DELAY;
  _hapticParams->cnt = 0;
  _hapticParams->waveform = NULL;

  pinMode(_hapticParams->pinPS, OUTPUT);
  pinMode(_hapticParams->pinEN, OUTPUT);
  pinMode(_hapticParams->pinDIR, OUTPUT);
  pinMode(_hapticParams->pinPWM, OUTPUT);
  digitalWrite(_hapticParams->pinPS, LOW);
  digitalWrite(_hapticParams->pinPWM, LOW);
  digitalWrite(_hapticParams->pinDIR, LOW);
  analogWrite(_hapticParams->pinEN, 0);
  pinMode(_hapticParams->pinPS, INPUT);
  pinMode(_hapticParams->pinEN, INPUT);
  pinMode(_hapticParams->pinDIR, INPUT);
  pinMode(_hapticParams->pinPWM, INPUT);
}

/* Reset the commands vector */
void resetCommandsVector(struct sVibrationERM *_hapticParams) {
  _hapticParams->commands.clear();
  _hapticParams->commandIndex = 0;
}

/* Haptic rendering function for ERM vibration */
void hapticRendering() {
  if (hapticParams.phase == PHASE_DELAY) {
    if (hapticParams.cnt == 0) {
      bool isCorrect;
      isCorrect = hapticCommandParser(hapticParams.commands[hapticParams.commandIndex]);
      if (!isCorrect) {
        resetHapticParams(&hapticParams);
        resetCommandsVector(&hapticParams);
        taskHapticRendering.disable();
        Serial.println("Wrong input command");
        return;
      }
    }
    if (hapticParams.cnt == hapticParams.initialDelay) {
      hapticParams.phase = PHASE_HAPTICGEN;
      hapticParams.cnt = 0;
    } else {
      hapticParams.cnt++;
    }
  }
  if (hapticParams.phase == PHASE_HAPTICGEN) {
    if (hapticParams.cnt == 0) {
      pinMode(hapticParams.pinPS, OUTPUT);
      pinMode(hapticParams.pinEN, OUTPUT);
      pinMode(hapticParams.pinDIR, OUTPUT);
      pinMode(hapticParams.pinPWM, OUTPUT);

      if (hapticParams.envelope == 0) { // flat
        hapticParams.waveform = wFlat;
      } else if (hapticParams.envelope == 1) { // Increase
        hapticParams.waveform = wIncrease;
      } else if (hapticParams.envelope == 2) { // Decrease
        hapticParams.waveform = wDecrease;
      } else if (hapticParams.envelope == 3) { // Decrease
        hapticParams.waveform = wIncreaseDecrease;
      }

      int arrNum = (hapticParams.cnt + 1) * WAVENUM / hapticParams.duration;
      int _intensity = (int)((float)hapticParams.intensity/10 * hapticParams.waveform[arrNum] + MINIMUNVALUE);
      digitalWrite(hapticParams.pinPS, HIGH);
      digitalWrite(hapticParams.pinPWM, HIGH);
      digitalWrite(hapticParams.pinDIR, LOW);
      
      analogWrite(hapticParams.pinEN, _intensity);
      hapticParams.cnt++;
    } else if (hapticParams.cnt >= hapticParams.duration) {
      resetHapticParams(&hapticParams);
      taskHapticRendering.disable();
      if (hapticParams.commandIndex < hapticParams.commands.size() - 1) {
        hapticParams.commandIndex++;
        taskHapticRendering.enable();
      } else {
        resetCommandsVector(&hapticParams);
        Serial.println("Vibration End");
      }
    } else {
      int arrNum = (hapticParams.cnt + 1) * WAVENUM / hapticParams.duration;
      int _intensity = (int)((float)hapticParams.intensity/10 * hapticParams.waveform[arrNum] + MINIMUNVALUE);
      analogWrite(hapticParams.pinEN, _intensity);
      hapticParams.cnt++;
    }
  }
}
#endif

/* Vibration (LRA) 
 * But, not implemented yet
 */
#ifdef VIBLRA
struct sVibrationLRA {
};
struct sVibrationLRA hapticParams;
#endif

/* Thermal Sensation */
#ifdef THERM
struct sThermal {
  int pinPS;
  int pinDIR;
  int pinEN;
  int pinPWM;
  int direction;
  int envelope;
  int intensity;
  int duration;
  int initialDelay;
  PHASE phase;
  int cnt;
  String storage_array[ELEMENT_COUNT_MAX];
  Vector<String> commands;
  int commandIndex;
  short *waveform;
};
struct sThermal hapticParams;

/* Haptic rendering function for thermal sensation */
void hapticRendering();
Task taskHapticRendering(100 * TASK_MILLISECOND, TASK_FOREVER, &hapticRendering); 

/* Reset haptic parameters for thermal sensation */
void resetHapticParams(struct sThermal *_hapticParams) {
  Serial.println("Reset Thermal Parameters");
  _hapticParams->envelope = 0;
  _hapticParams->direction = 0;
  _hapticParams->intensity = 0;
  _hapticParams->duration = 0;
  _hapticParams->cnt = 0;
  _hapticParams->initialDelay = 0;
  _hapticParams->phase = PHASE_DELAY;
  _hapticParams->cnt = 0;
  _hapticParams->waveform = NULL;

  pinMode(_hapticParams->pinPS, OUTPUT);
  pinMode(_hapticParams->pinEN, OUTPUT);
  pinMode(_hapticParams->pinDIR, OUTPUT);
  pinMode(_hapticParams->pinPWM, OUTPUT);
  digitalWrite(_hapticParams->pinPS, LOW);
  digitalWrite(_hapticParams->pinPWM, LOW);
  digitalWrite(_hapticParams->pinDIR, LOW);
  analogWrite(_hapticParams->pinEN, 0);
  pinMode(_hapticParams->pinPS, INPUT);
  pinMode(_hapticParams->pinEN, INPUT);
  pinMode(_hapticParams->pinDIR, INPUT);
  pinMode(_hapticParams->pinPWM, INPUT);
}

/* Reset the commands vector */
void resetCommandsVector(struct sThermal *_hapticParams) {
  _hapticParams->commands.clear();
  _hapticParams->commandIndex = 0;
}

/* Haptic rendering function for thermal sensation */
void hapticRendering() {
  if (hapticParams.phase == PHASE_DELAY) {
    if (hapticParams.cnt == 0) {
      bool isCorrect;
      isCorrect = hapticCommandParser(hapticParams.commands[hapticParams.commandIndex]);
      if (!isCorrect) {
        resetHapticParams(&hapticParams);
        resetCommandsVector(&hapticParams);
        taskHapticRendering.disable();
        Serial.println("Wrong input command");
        return;
      }
    }
    if (hapticParams.cnt == hapticParams.initialDelay) {
      hapticParams.phase = PHASE_HAPTICGEN;
      hapticParams.cnt = 0;
    } else {
      hapticParams.cnt++;
    }
  }
  if (hapticParams.phase == PHASE_HAPTICGEN) {
    if (hapticParams.cnt == 0) {
      pinMode(hapticParams.pinPS, OUTPUT);
      pinMode(hapticParams.pinEN, OUTPUT);
      pinMode(hapticParams.pinDIR, OUTPUT);
      pinMode(hapticParams.pinPWM, OUTPUT);

      int _intensity = hapticParams.intensity * 20;
      digitalWrite(hapticParams.pinPS, HIGH);
      digitalWrite(hapticParams.pinPWM, HIGH);
      if (hapticParams.envelope == 0) {  // !CHANGE!
        digitalWrite(hapticParams.pinDIR, LOW); // 22 - HIGH, 21 - LOW
      } else if (hapticParams.envelope == 1) {
        digitalWrite(hapticParams.pinDIR, HIGH);
      }
      analogWrite(hapticParams.pinEN, _intensity);
      hapticParams.cnt++;
    } else if (hapticParams.cnt >= hapticParams.duration) {
      resetHapticParams(&hapticParams);
      taskHapticRendering.disable();
      if (hapticParams.commandIndex < hapticParams.commands.size() - 1) {
        hapticParams.commandIndex++;
        taskHapticRendering.enable();
      } else {
        resetCommandsVector(&hapticParams);
        Serial.println("Thermal Sensation End");
      }
    } else {
      int _intensity = hapticParams.intensity * 20;
      analogWrite(hapticParams.pinEN, _intensity);

      hapticParams.cnt++;
    }
  }
}
#endif

/* Variable Inertia */
#ifdef VMASS
struct sVariableMass {
  int pinPS;
  int pinDIR;
  int pinEN;
  int pinPWM;
  int direction;
  int distance;
  int initialDelay;
  int cnt;
  PHASE phase;
  String storage_array[ELEMENT_COUNT_MAX];
  Vector<String> commands;
  int commandIndex;
};
struct sVariableMass hapticParams;;

/* Haptic rendering function for variable inertia */
void hapticRendering();
Task taskHapticRendering(100 * TASK_MILLISECOND, TASK_FOREVER, &hapticRendering);

/* Reset haptic parameters for variable inertia */
void resetHapticParams(struct sVariableMass *_hapticParams) {
  Serial.println("Reset Variable Mass Parameters");
  _hapticParams->direction = 0;
  _hapticParams->distance = 0;
  _hapticParams->cnt = 0;
  _hapticParams->initialDelay = 0;
  _hapticParams->phase = PHASE_DELAY;

  pinMode(_hapticParams->pinPS, OUTPUT);
  pinMode(_hapticParams->pinEN, OUTPUT);
  pinMode(_hapticParams->pinDIR, OUTPUT);
  pinMode(_hapticParams->pinPWM, OUTPUT);
  digitalWrite(_hapticParams->pinPS, LOW);
  digitalWrite(_hapticParams->pinPWM, LOW);
  digitalWrite(_hapticParams->pinDIR, LOW);
  analogWrite(_hapticParams->pinEN, 0);
  pinMode(_hapticParams->pinPS, INPUT);
  pinMode(_hapticParams->pinEN, INPUT);
  pinMode(_hapticParams->pinDIR, INPUT);
  pinMode(_hapticParams->pinPWM, INPUT);
}

/* Reset the commands vector */
void resetCommandsVector(struct sVariableMass *_hapticParams) {
  _hapticParams->commands.clear();
  _hapticParams->commandIndex = 0;
}

/* Haptic rendering function for variable inertia */
void hapticRendering() {
  if (hapticParams.phase == PHASE_DELAY) {
    if (hapticParams.cnt == 0) {
      bool isCorrect;
      isCorrect = hapticCommandParser(hapticParams.commands[hapticParams.commandIndex]);
      if (!isCorrect) {
        resetHapticParams(&hapticParams);
        resetCommandsVector(&hapticParams);
        taskHapticRendering.disable();
        return;
      }
    }
    if (hapticParams.cnt == hapticParams.initialDelay) {
      hapticParams.phase = PHASE_HAPTICGEN;
      hapticParams.cnt = 0;
    } else {
      hapticParams.cnt++;
    }
  }
  if (hapticParams.phase == PHASE_HAPTICGEN) {
    if (hapticParams.cnt == 0) {
      pinMode(hapticParams.pinPS, OUTPUT);
      pinMode(hapticParams.pinEN, OUTPUT);
      pinMode(hapticParams.pinDIR, OUTPUT);
      pinMode(hapticParams.pinPWM, OUTPUT);

      digitalWrite(hapticParams.pinPS, HIGH);
      digitalWrite(hapticParams.pinPWM, HIGH);
      if (hapticParams.direction == 0 || hapticParams.direction == 2) {
        digitalWrite(hapticParams.pinDIR, LOW);
      } else {
        digitalWrite(hapticParams.pinDIR, HIGH);
      }
      analogWrite(hapticParams.pinEN, 255);

      hapticParams.cnt++;
    } else if (hapticParams.cnt >= hapticParams.distance) {
      resetHapticParams(&hapticParams);
      taskHapticRendering.disable();
      if (hapticParams.commandIndex < hapticParams.commands.size() - 1) {
        hapticParams.commandIndex++;
        taskHapticRendering.enable();
      } else {
        resetCommandsVector(&hapticParams);
        Serial.println("Vmass End");
      }
    } else {
      hapticParams.cnt++;
      if (hapticParams.direction == 2) { // Initialization
        int voltage_ = analogRead(A0);
        Serial.println(voltage_);
        if (voltage_ > 20) {
          resetHapticParams(&hapticParams);
          resetCommandsVector(&hapticParams);
          taskHapticRendering.disable();
          Serial.println("Vmass End");
        }
      }
    }
  }
}
#endif

/* Impact Sensation */
#ifdef IMPACT
struct sImpact {
  int pin;
  int isGen;
  int cnt;
  int duration;
  int initialDelay;
  int impCnt;
  PHASE phase;
  bool direction = true;
  String storage_array[ELEMENT_COUNT_MAX];
  Vector<String> commands;
  int commandIndex;
};
struct sImpact hapticParams;

const int impactDuration = 5;
/* Haptic rendering function for impact sensation */
void hapticRendering();
Task taskHapticRendering(10 * TASK_MILLISECOND, TASK_FOREVER, &hapticRendering); 

/* Reset haptic parameters for impact sensation */
void resetHapticParams(struct sImpact *_hapticParams) {
  Serial.println("Reset Impact Parameters");
  _hapticParams->isGen = false;
  _hapticParams->cnt = false;
  _hapticParams->initialDelay = 0;
  _hapticParams->impCnt = 0;
  _hapticParams->phase = PHASE_DELAY;
}

/* Reset the commands vector */
void resetCommandsVector(struct sImpact *_hapticParams) {
  _hapticParams->commands.clear();
  _hapticParams->commandIndex = 0;
}

/* Haptic rendering function for impact sensation */
void hapticRendering() {
  if (hapticParams.phase == PHASE_DELAY) {
    if (hapticParams.cnt == 0) {
      hapticCommandParser(hapticParams.commands[hapticParams.commandIndex]);
    }
    if (hapticParams.cnt == hapticParams.initialDelay*10) {
      hapticParams.phase = PHASE_HAPTICGEN;
      hapticParams.cnt = 0;
    } else {
      hapticParams.cnt++;
    }
  }
  if (hapticParams.phase == PHASE_HAPTICGEN) {
    if (hapticParams.cnt == 0) {
      pinMode(hapticParams.pin, OUTPUT);
      if (hapticParams.direction) {
        digitalWrite(hapticParams.pin, HIGH);
      } else {
        digitalWrite(hapticParams.pin, LOW);
      }
      hapticParams.cnt++;
    } else if (hapticParams.cnt == impactDuration) {
      pinMode(hapticParams.pin, INPUT);
      hapticParams.cnt++;
    } else if (hapticParams.cnt == impactDuration + 1) {
      resetHapticParams(&hapticParams);
      hapticParams.direction = !hapticParams.direction;
      taskHapticRendering.disable();
      if (hapticParams.commandIndex < hapticParams.commands.size() - 1) {
        hapticParams.commandIndex++;
        taskHapticRendering.enable();
      } else {
        resetCommandsVector(&hapticParams);
        Serial.println("Impact End");
      }
    } else {
      hapticParams.cnt++;
    }
  }
}
#endif

/* Variable Stiffness */
#ifdef VSTIFF
struct sVariableStiff {
  int pinPS;
  int pinDIR;
  int pinEN;
  int pinPWM;
  int envelope;
  int intensity;
  int duration;
  int initialDelay;
  PHASE phase;
  int cnt;
  String storage_array[ELEMENT_COUNT_MAX];
  Vector<String> commands;
  int commandIndex;
};
struct sVariableStiff hapticParams;

/* Haptic rendering function for variable stiffness */
void hapticRendering();
Task taskHapticRendering(100 * TASK_MILLISECOND, TASK_FOREVER, &hapticRendering); 

/* Reset haptic parameters for variable stiffness */
void resetHapticParams(struct sVariableStiff *_hapticParams) {
  Serial.println("Reset VStiff Parameters");
  _hapticParams->envelope = 0;
  _hapticParams->intensity = 0;
  _hapticParams->duration = 0;
  _hapticParams->cnt = 0;
  _hapticParams->initialDelay = 0;
  _hapticParams->phase = PHASE_DELAY;
  _hapticParams->cnt = 0;

  pinMode(_hapticParams->pinPS, OUTPUT);
  pinMode(_hapticParams->pinEN, OUTPUT);
  pinMode(_hapticParams->pinDIR, OUTPUT);
  pinMode(_hapticParams->pinPWM, OUTPUT);
  digitalWrite(_hapticParams->pinPS, LOW);
  digitalWrite(_hapticParams->pinPWM, LOW);
  digitalWrite(_hapticParams->pinDIR, LOW);
  analogWrite(_hapticParams->pinEN, 0);
  pinMode(_hapticParams->pinPS, INPUT);
  pinMode(_hapticParams->pinEN, INPUT);
  pinMode(_hapticParams->pinDIR, INPUT);
  pinMode(_hapticParams->pinPWM, INPUT);
}

/* Reset the commands vector */
void resetCommandsVector(struct sVariableStiff *_hapticParams) {
  _hapticParams->commands.clear();
  _hapticParams->commandIndex = 0;
}

/* Haptic rendering function for variable stiffness */
void hapticRendering() {
  if (hapticParams.phase == PHASE_DELAY) {
    if (hapticParams.cnt == 0) {
      bool isCorrect;
      isCorrect = hapticCommandParser(hapticParams.commands[hapticParams.commandIndex]);
      if (!isCorrect) {
        resetHapticParams(&hapticParams);
        resetCommandsVector(&hapticParams);
        taskHapticRendering.disable();
        Serial.println("Wrong input command");
        return;
      }
    }
    if (hapticParams.cnt == hapticParams.initialDelay) {
      hapticParams.phase = PHASE_HAPTICGEN;
      hapticParams.cnt = 0;
    } else {
      hapticParams.cnt++;
    }
  }
  if (hapticParams.phase == PHASE_HAPTICGEN) {
    if (hapticParams.cnt == 0) {
      pinMode(hapticParams.pinPS, OUTPUT);
      pinMode(hapticParams.pinEN, OUTPUT);
      pinMode(hapticParams.pinDIR, OUTPUT);
      pinMode(hapticParams.pinPWM, OUTPUT);

      int _intensity = hapticParams.intensity * 20;
      digitalWrite(hapticParams.pinPS, HIGH);
      digitalWrite(hapticParams.pinPWM, HIGH);
      digitalWrite(hapticParams.pinDIR, HIGH);
      analogWrite(hapticParams.pinEN, _intensity);
      hapticParams.cnt++;
    } else if (hapticParams.cnt >= 50) {
      resetHapticParams(&hapticParams);
      taskHapticRendering.disable();
      if (hapticParams.commandIndex < hapticParams.commands.size() - 1) {
        hapticParams.commandIndex++;
        taskHapticRendering.enable();
      } else {
        resetCommandsVector(&hapticParams);
        Serial.println("Vstiff End");
      }
    } else {
      hapticParams.cnt++;
    }
  }
}
#endif

/* Touch */
#ifdef TOUCH
int touchPin;
int capThreshold = 8;
bool isTouched = false;

/* Check capacitance for touch detection */
void checkCapacitacne();
Task taskReadCapacitance(100 * TASK_MILLISECOND, TASK_FOREVER, &checkCapacitacne); // every 0.25 seconds

/* Check capacitance for touch detection */
void checkCapacitacne() {
  int cap = analogRead(touchPin);
  Serial.println(cap);

  if (!isTouched && cap >= capThreshold) {
    isTouched = true;
    mesh.sendBroadcast("CO"); // Contact ON
  } else if (isTouched && cap < capThreshold) {
    isTouched = false;
    mesh.sendBroadcast("CF"); // Contact OFF
  }
}
#endif

/* Button */
#ifdef BUTTON
int buttonPin;
int buttonThreshold = 100;
bool isPressed = false;

/* Check button press status */
void checkButtonPress();
Task taskCheckButtonPress(50 * TASK_MILLISECOND, TASK_FOREVER, &checkButtonPress); // every 0.25 seconds

/* Check button press status */
void checkButtonPress() {
  int _button = analogRead(buttonPin);
  

  if (!isPressed && _button >= buttonThreshold) {
    isPressed = true;
    mesh.sendBroadcast("CO"); // Contact ON
  } else if (isPressed && _button < buttonThreshold) {
    isPressed = false;
    mesh.sendBroadcast("CF"); // Contact OFF
  }
}
#endif

/* Initialize variables for haptic parameters and commands */
void initVariables() {
  #if defined(VIBERM) || defined(THERM) || defined(VMASS) || defined(IMPACT) || defined(VSTIFF)
  hapticParams.commands.setStorage(hapticParams.storage_array);
  resetHapticParams(&hapticParams);
  resetCommandsVector(&hapticParams);
  #endif
  #ifdef IMPACT
  hapticParams.direction = false;
  hapticParams.commands.push_back("P00");
  hapticParams.commands.push_back("P00");
  taskHapticRendering.enable();
  #endif
}
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
void loop() {
  mesh.update();
}

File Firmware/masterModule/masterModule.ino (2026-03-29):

/****
 *  Firmware for HaptiCraft (IEEE TVCG 2026)
 *  Author: Chaeyong Park
 *  Copyright (c): 2026. AXIS Laboratory, Korea University
 *  WEMOS D1 MINI (ESP8266)
 * 
 *  Master module
 *  - The master module is responsible for receiving the commands from the user and sending the commands to the corresponding haptic modules.
 *  - The master module also manages the connected haptic modules and their states.
 *  - The communication between the master module and the haptic modules is done through the WiFi mesh network using the painlessMesh library.
 *  - The master module receives the commands from the user through the serial communication and parses the commands to send the corresponding commands to the haptic modules.
 *  
 *  The command format is as follows:
 *  $N1C1,N2C2 ...
 *  NX: Name of a module to operate
 *  CX: The command of the module
 *
 */
#include "painlessMesh.h"
#include <Vector.h>

#define MESH_PREFIX "modularHaptics"
#define MESH_PASSWORD "somethingSneaky"
#define MESH_PORT 5555
#define NODE_COUNT_MAX 20
#define CEHCK_THRESHOLD 2

/* A new data structure */
typedef struct {
  uint32_t nodeID;
  String nodeName;
  bool check;
} Node;

/* Serial Communication */
String inString;

/* Node Information */
String nodeName = "MM";
Node storage_array[NODE_COUNT_MAX];
Vector<Node> connectedNodes;
int isCheck = 0;
int nodeNum = 0;

/* General Information */
bool isTouched = false;

/* Task Functions */
Scheduler userScheduler;  // to control your personal task
void checkAndRemoveNode();
Task taskRemoveNode(TASK_SECOND * 3, TASK_FOREVER, &checkAndRemoveNode);
//void serialTransfer();
//Task taskSerialTransfer(TASK_SECOND, TASK_FOREVER, &serialTransfer);

/* General Functions */
String getNodeNameFromID(Vector<Node> *v, uint32_t _nodeID);
void setNodeCheck(uint32_t _nodeID);
void checkAndUpdateNode(uint32_t _nodeID, String _nodeName);
void removeNode(uint32_t _nodeID);
void removeAllNodes();
void showConnectedList(bool isMesh);
int numberOfConnectedMesh(bool isMesh);

/* Functions for WiFi mesh network */
painlessMesh mesh;
void receivedCallback(uint32_t _nodeID, String &msg);
void newConnectionCallback(uint32_t _nodeID);
void changedConnectionCallback();
void droppedConnectionCallback(uint32_t _nodeID);

/* Get the node name from the node ID */
String getNodeNameFromID(uint32_t _nodeID) {
  for (int i = 0; i < nodeNum; i++) {
    if (connectedNodes[i].nodeID == _nodeID) {
      return connectedNodes[i].nodeName;
    }
  }
}

/* Set the check value of the node to true when the node is connected */
void setNodeCheck(uint32_t _nodeID) {
  int sizeVector = connectedNodes.size();
  for (int i = 0; i < sizeVector; i++) {
    if (connectedNodes[i].nodeID == _nodeID) {
      connectedNodes[i].check = true;
    }
  }
}

/* Check the node connection and update the node information if the node is already connected. 
 * If the node is not connected, add the node to the connected node list */
void checkAndUpdateNode(uint32_t _nodeID, String _nodeName = "NN") {
  int sizeVector = connectedNodes.size();
  int sizeMesh = mesh.getNodeList().size();
  int flagExist = false;

  if (sizeVector <= sizeMesh) { // Need to add a new node
    for (int i = 0; i < sizeVector; i++) {
      if (connectedNodes[i].nodeID == _nodeID) {
        flagExist = true;
        if (connectedNodes[i].nodeName != _nodeName) {
          connectedNodes[i].nodeName = _nodeName;
          Serial.printf("UPDATE MODULE: ID-%u NAME-%s\n", _nodeID, _nodeName);
          break;
        }
      }
    }
    if (!flagExist) {
      connectedNodes.push_back({_nodeID, _nodeName, true});
      nodeNum++;
      Serial.printf("NEW MODULE: ID-%u NAME-%s\n", _nodeID, _nodeName);
      String _command = "#C" + _nodeName + "\n";
      Serial.printf(_command.c_str());
    }
  }
}

/* Check the node connection and remove the node if it is not connected */
void checkAndRemoveNode() {
  if (isCheck == CEHCK_THRESHOLD){
    int sizeVector = connectedNodes.size();
    int sizeMesh = mesh.getNodeList().size();

    for (int i = 0; i < sizeVector; i++) { // Remove
      if (connectedNodes[i].check) {
        connectedNodes[i].check = false;
      } else {
        Serial.printf("REMOVE NODE ID: %u Name: %s\n", connectedNodes[i].nodeID, connectedNodes[i].nodeName.c_str());
        String _command = "#D" + connectedNodes[i].nodeName + "\n";
        Serial.printf(_command.c_str());
        connectedNodes.remove(i);
        nodeNum--;
      }
    }
    if (sizeVector < sizeMesh) { // Check the difference between the number of mesh and vector
      SimpleList<uint32_t> nodes = mesh.getNodeList();
      SimpleList<uint32_t>::iterator _node = nodes.begin();
      while(_node != nodes.end()) {
        uint32_t _nodeID = *(_node);
        bool existInNode = false;
        for (int i = 0; i < sizeVector; i++) {
          if (connectedNodes[i].nodeID == _nodeID) {
            existInNode = true;
            break;
          }
        }
        if (!existInNode) {
          mesh.sendBroadcast("I");
          break;
        }
        _node++;
      }
    }
    
  } else {
    mesh.sendBroadcast("D");
  }

  isCheck++;
  if (isCheck > CEHCK_THRESHOLD) {
    isCheck = 0; 
  }
}

/* Just for test */
void serialTransfer() {
  Serial.printf("z\n");
}

/* Remove the node if it is not connected */
void removeNode(uint32_t _nodeID) {
  for (int i = 0; i < nodeNum; i++) {
    if (connectedNodes[i].nodeID == _nodeID) {
      Serial.printf("REMOVE NODE ID: %u Name: %s\n", connectedNodes[i].nodeID, connectedNodes[i].nodeName.c_str());
      String _command = "#D" + connectedNodes[i].nodeName + "\n";
      Serial.printf(_command.c_str());
      connectedNodes.remove(i);
      nodeNum--;
      break;
    }
  }
}

/* Remove all nodes */
void removeAllNodes() {
  connectedNodes.clear();
  nodeNum = 0;
}

/* Show the connected nodes */
void showConnectedMesh(bool isMesh = false) {
  if (isMesh) {
    SimpleList<uint32_t> nodes = mesh.getNodeList();
    SimpleList<uint32_t>::iterator _node = nodes.begin();
    int cnt = 1;
    while(_node != nodes.end()) {
      Serial.printf("%d: ID-%u\n", cnt++, *(_node));
      _node++;
    }
  } else {
    int _size = connectedNodes.size();
    for (int i = 0; i < _size; i++) {
      Serial.printf("%d: ID-%u NAME-%s\n", i+1, connectedNodes[i].nodeID, connectedNodes[i].nodeName);
    }
  }
}

/* Show the number of connected nodes */
int numberOfConnectedMesh(bool isMesh = false) {
  if (isMesh) {
    return mesh.getNodeList().size();
  } else {
    return connectedNodes.size();
  }
}
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

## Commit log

2026-03-29 Add CAD files for the entire modules
    [10_moving mass ring.STL, 11_screw.STL, 1_bottom-single side.STL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]
2026-03-31 Add the variable damping actuator CAD files
    [1_spring base.STL, 2_spring.STL, 3_coil.STL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]
2026-04-02 Add schematics and the corresponding descriptions
2026-04-02 modify the image size for schematic
